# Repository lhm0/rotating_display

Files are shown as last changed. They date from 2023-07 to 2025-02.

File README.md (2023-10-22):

# Rotating Display

## Abstract: 
 The Rotating Display is a compact disc-sized device that rotates quietly using a CD motor. It features 40 LEDs that display time and weather data sourced from the internet. The device is wirelessly powered and controlled via a user-friendly web interface. It uses Arduino nano and ESP-01s microcontrollers and is easy to assemble.
 
<p align="center"> 
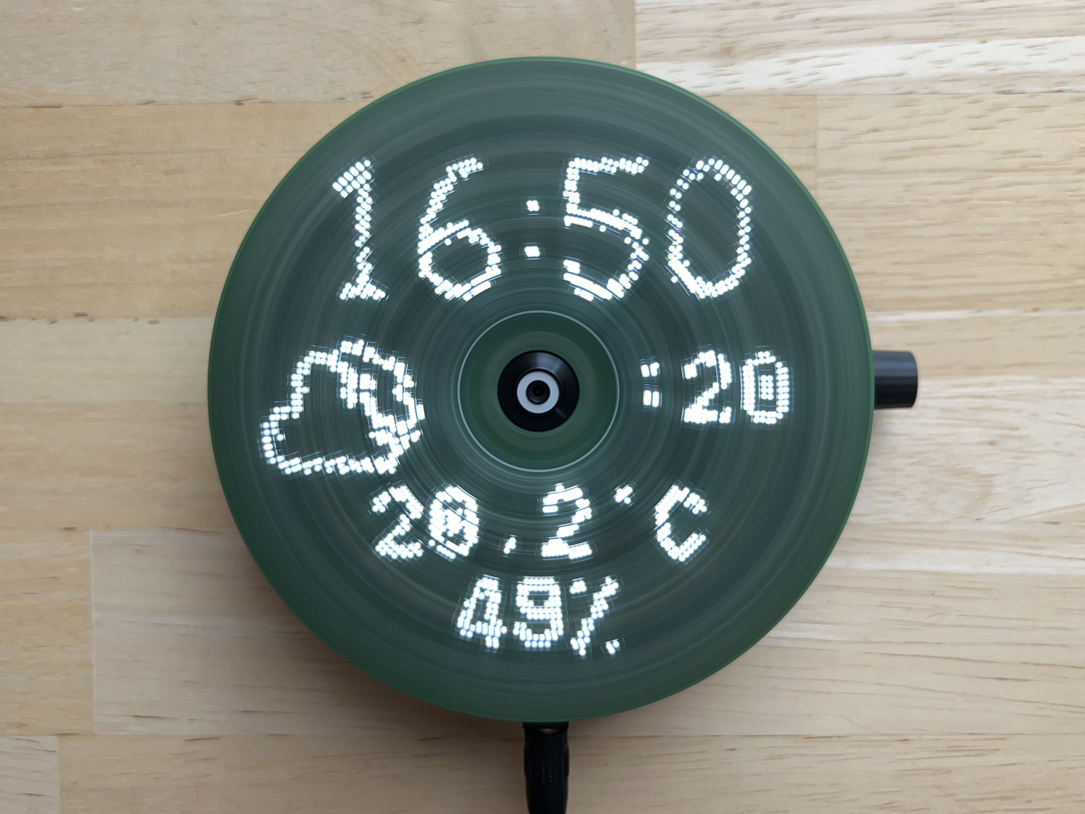
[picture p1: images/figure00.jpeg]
  
</p>

<p align="center"> 
<a href="https://youtu.be/7XahXYzULtI?si=OmdDaNnT-Jkq3F4Q" target="_blank">
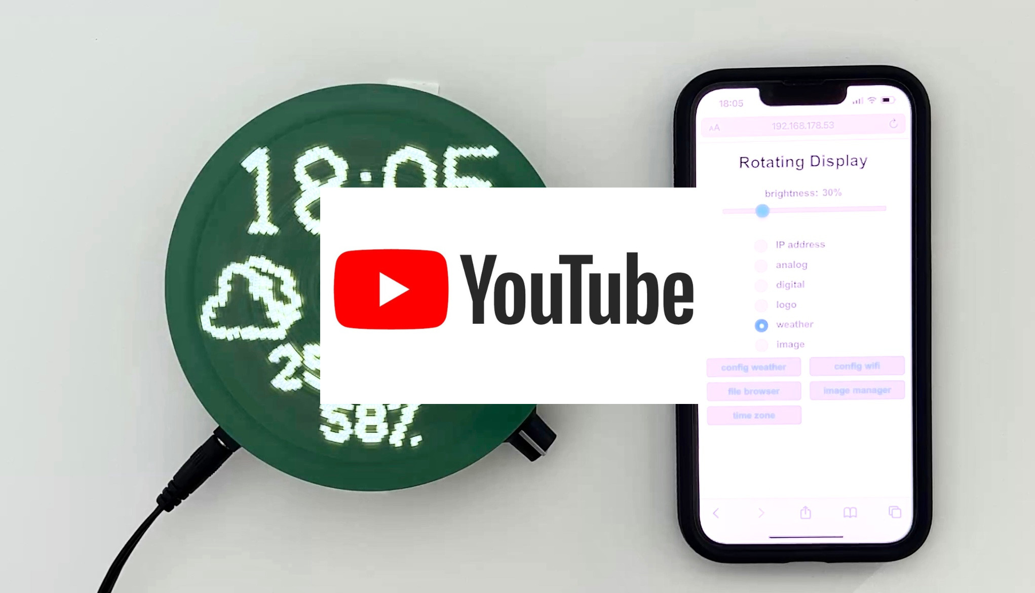
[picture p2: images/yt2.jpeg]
  
</a>
</p> 

<p align="center"> 
<a href="https://youtu.be/tHjmvry00_w?si=LjtpMpMhL_XMzbsv" target="_blank">
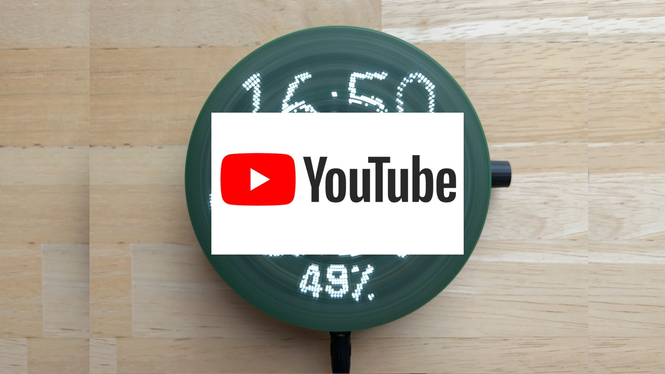
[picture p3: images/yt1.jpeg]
  
</a>
</p> 

## 1. Description of the device

The Rotating Display device comprises two primary units: a power supply unit and a display board (**figure 1**). Both are circular in design, with a diameter of 120mm, similar to the dimensions of a standard Compact Disk. The display board is rotated by a CD motor. Energy is wirelessly transmitted from the power supply unit to the display board, eliminating the need for wired connections.

<p align="center"> 
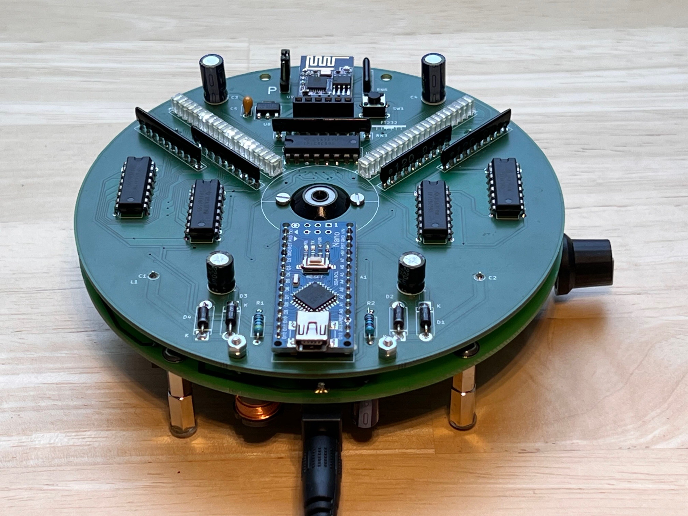
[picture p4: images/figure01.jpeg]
  
</p>

**Figure 1:  Rotating Display assembly.** The lower PCB is the power supply with wireless power transmission, the upper PCB is the display board.

The display board is equipped with two rows of LEDs, each containing 20 LEDs. This makes a total of 40 LEDs available for image representation. The LED operations are controlled by an Arduino Nano, while an ESP-01s microcontroller generates the display content. The ESP-01s maintains a Wi-Fi connection to the internet for this purpose.

This internet connection allows the device to retrieve the time from a time server, ensuring time accuracy. It also allows for the acquisition of weather data. Device operation is managed through a web interface (**figure 2**), accessible from any web browser. The interface allows users to manage login credentials, upload image files to the display, and control image and configuration files through a file manager.

<p align="center"> 
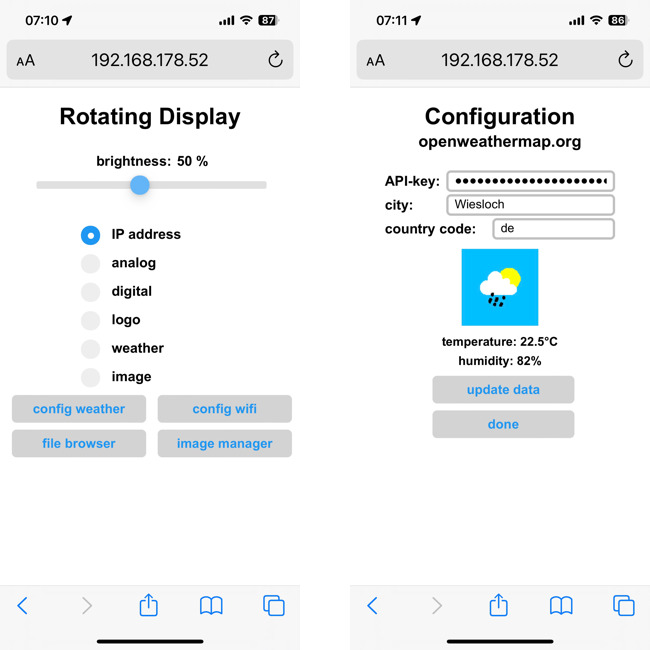
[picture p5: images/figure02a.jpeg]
  
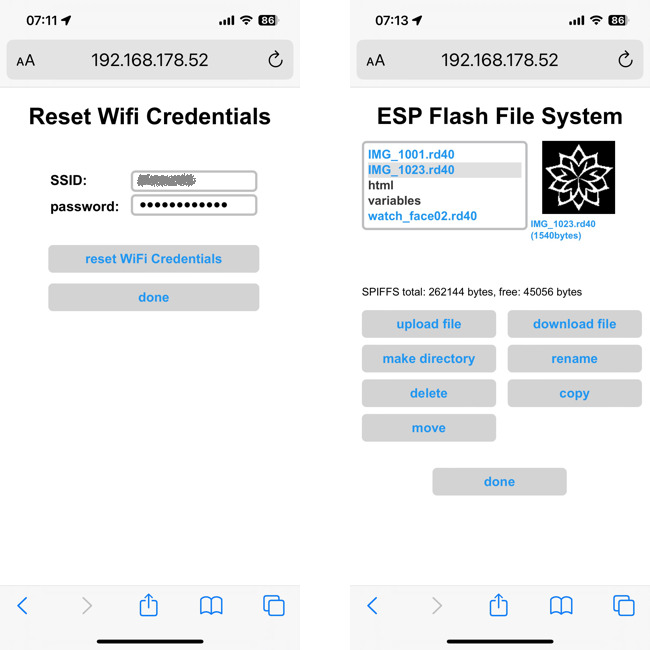
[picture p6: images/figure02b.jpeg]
  
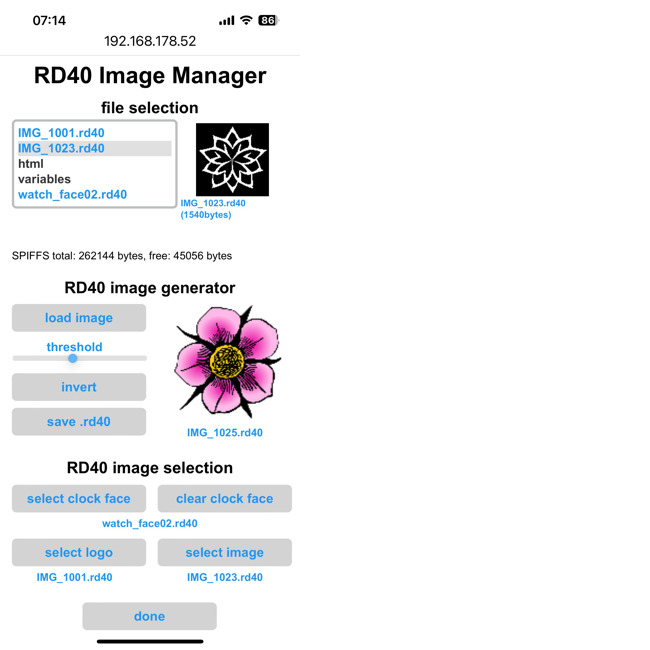
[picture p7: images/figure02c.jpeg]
  
</p>

**Figure 2:** The **web user interface** allows for operating mode selection and device configuration.

## 2. Operating modes

When switched on, the device tries to connect to a known wifi. If no valid wifi credentials are found, the unit will be configured as wifi access point. In this mode, a computer or mobile device can be connected, directly (SSID: RD40, no password). 

Once the wifi connection has been established, the unit will display its IP address on the  home page of the device (**figure 3**). Enter this address in your web browser. This will load the web user interface and will allow you to configure your local wifi.

<p align="center"> 
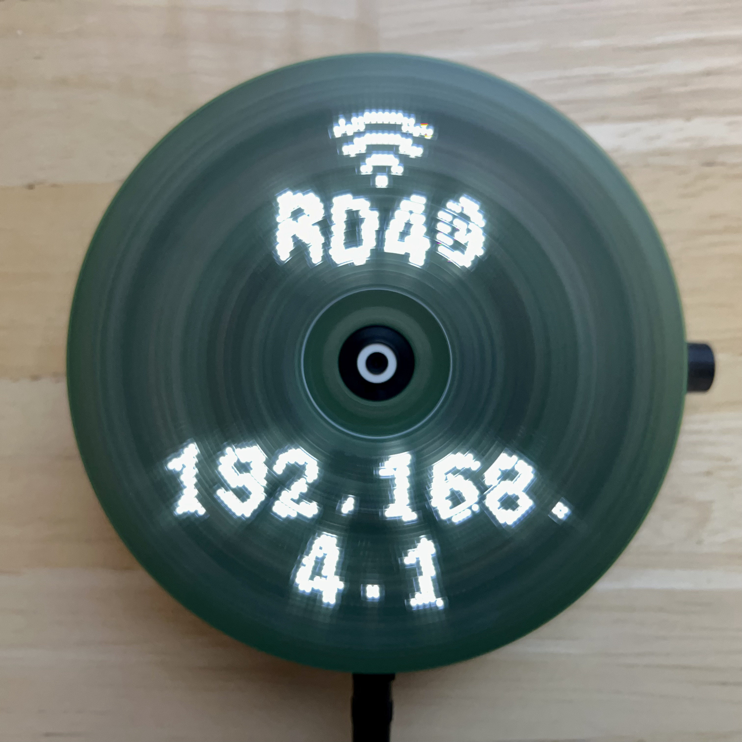
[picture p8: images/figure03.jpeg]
  
</p>

**Figure 3: home page.**

There are several operating modes that display time and weather information (**figure 4**). The logo clock mode integrates a customizable image into the clock face. The image can be easily uploaded from the user interface. The same is true for the analog clock, which uses a customizable clock face in the background.

<p align="center"> 
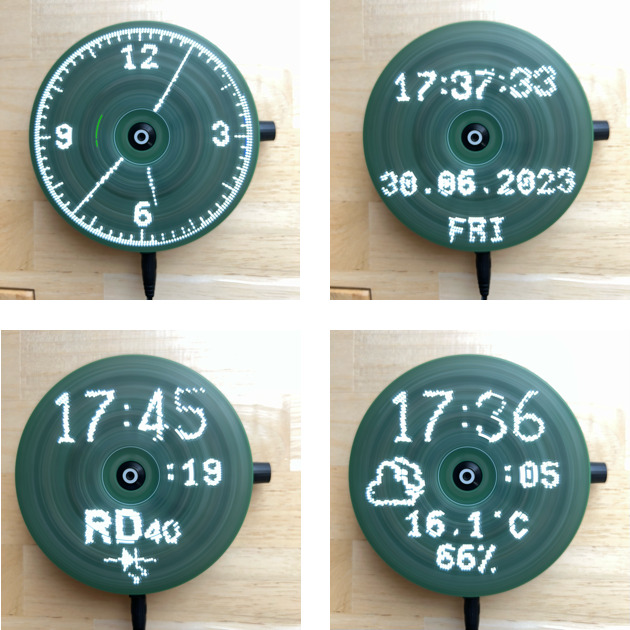
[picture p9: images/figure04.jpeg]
  
</p>

**Figure 4: operating modes.** Modes can be selected and configured through the web interface.

## 3. Mechanical design

The device consists of two assemblies: power supply and display. The power supply board is also the base plate, which can either be placed on a flat surface or hung on a wall. A standard CD motor is inserted through a recess in this board so that the CD tray above the board can accommodate the display assembly. The display board is fixed with two M2 screws. Furthermore, the base plate carries a potentiometer to control the motor speed as well as an on/off switch for the motor.

<p align="center"> 
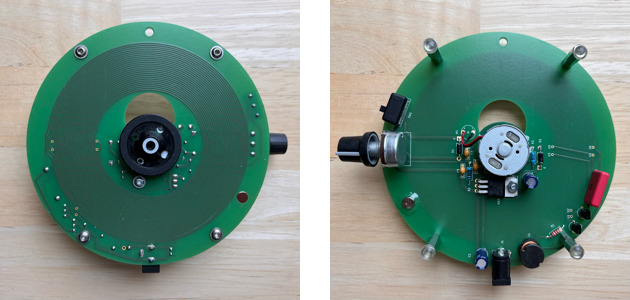
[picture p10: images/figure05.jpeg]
  
</p>

**Figure 5: Power Supply Board** with CD motor (middle), 12V power jack (lower side), and speed potentiometer

An important requirement for the display board is that the center of mass of the unit is exactly in the middle, on the axis of rotation of the motor. This is the only way to ensure smooth and vibration-free running of the display. To achieve this, the electronic components are arranged as symmetrically as possible to the vertical axis of symmetry in **figure 7**. This initially ensures that the center of gravity lies on this vertical axis. However, since the components cannot be distributed symmetrically to the horizontal axis of symmetry, the center of gravity must be shifted to the center along this axis using balancing weights. For this purpose, two M2x6mm screws with two nuts each are placed to the right and left of the Arduino nano. The balancing result is very good, but can certainly be further optimized.

<p align="center"> 
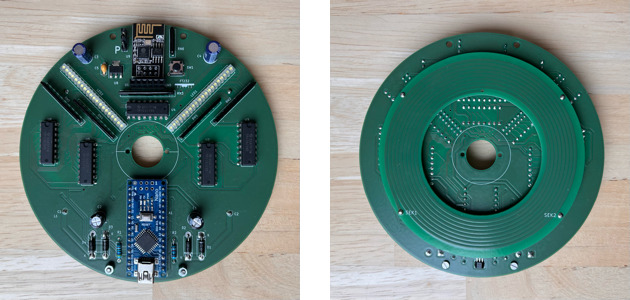
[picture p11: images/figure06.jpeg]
  
</p>

**Figure 6: Display Board.** Main components are the two LED rows, five serial shift register chips, and two microcontrollers (Arduino nano and ESP-01s). On the backside of the board the secondary coil of the wireless power supply is attached.

<p align="center"> 
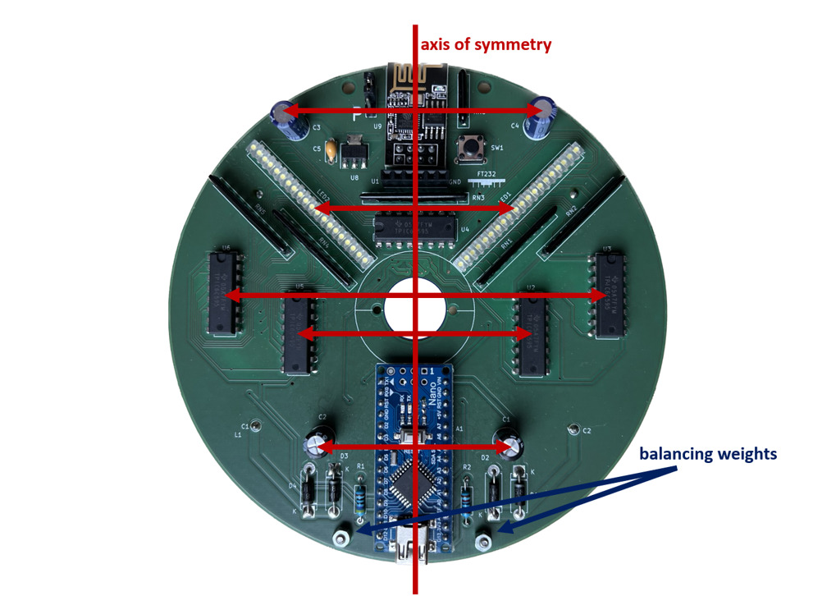
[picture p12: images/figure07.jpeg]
  
</p>

**Figure 7:** The components of the display board are arranged symmetrically to the vertical axis of symmetry. Therefore, the center of gravity is located on this axis. The vertical position of the center of gravity is adjusted to the middle by means of adjustment weights.

The two LED rows each consist of 20 discrete, rectangular LEDs. The components each have a width of 2mm and can be lined up without spacing. However, the light emitting surface of the LEDs has a diameter of only about 1mm. Thus, there is a 1mm gap between the light points. To fill these gaps, the second row of LEDs is used. It is inclined by 90 degrees along the angle of rotation. Radially, the two LED rows are shifted by 1 mm, creating a dot pattern without gaps (**figure 8**).

<p align="center"> 
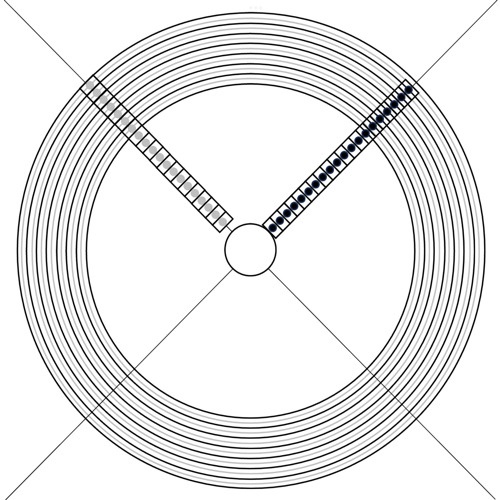
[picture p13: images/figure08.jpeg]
  
</p>

**Figure 8:** The two LED rows are displaced radially by half a LED width

The LEDs must output the image information at exactly the right position with each rotation. For spatial alignment of the image, a trigger signal is generated at a defined position for each rotation, which triggers the sequential, clocked output of the pixels. The trigger signal must be spatially very stable, otherwise no smooth image can be generated. It turned out that a Hall sensor is best suited for this purpose. It is located underneath the Arduino nano (see **figure 6**, right picture, bottom edge of the PCB). The magnet is glued into a hole of the power supply PCB (see figure 5, left picture, 4 o'clock position).

## 4. Electronics architecture

The distribution of the electronic circuitry between the two assemblies is shown in **figure 9**. The power supply assembly contains a Royer converter for wireless power transfer to the display assembly and an adjustment of the motor speed. The 40 LEDs of the display assembly are controlled by 5 shift registers (8 bits each), which in turn are supplied with clock and data by an Arduino nano via an SPI interface. The displayed content is generated by an ESP-01s microcontroller, which is connected to the internet via Wifi. It transmits its data to the Arduino nano via an I2C interface.

<p align="center"> 
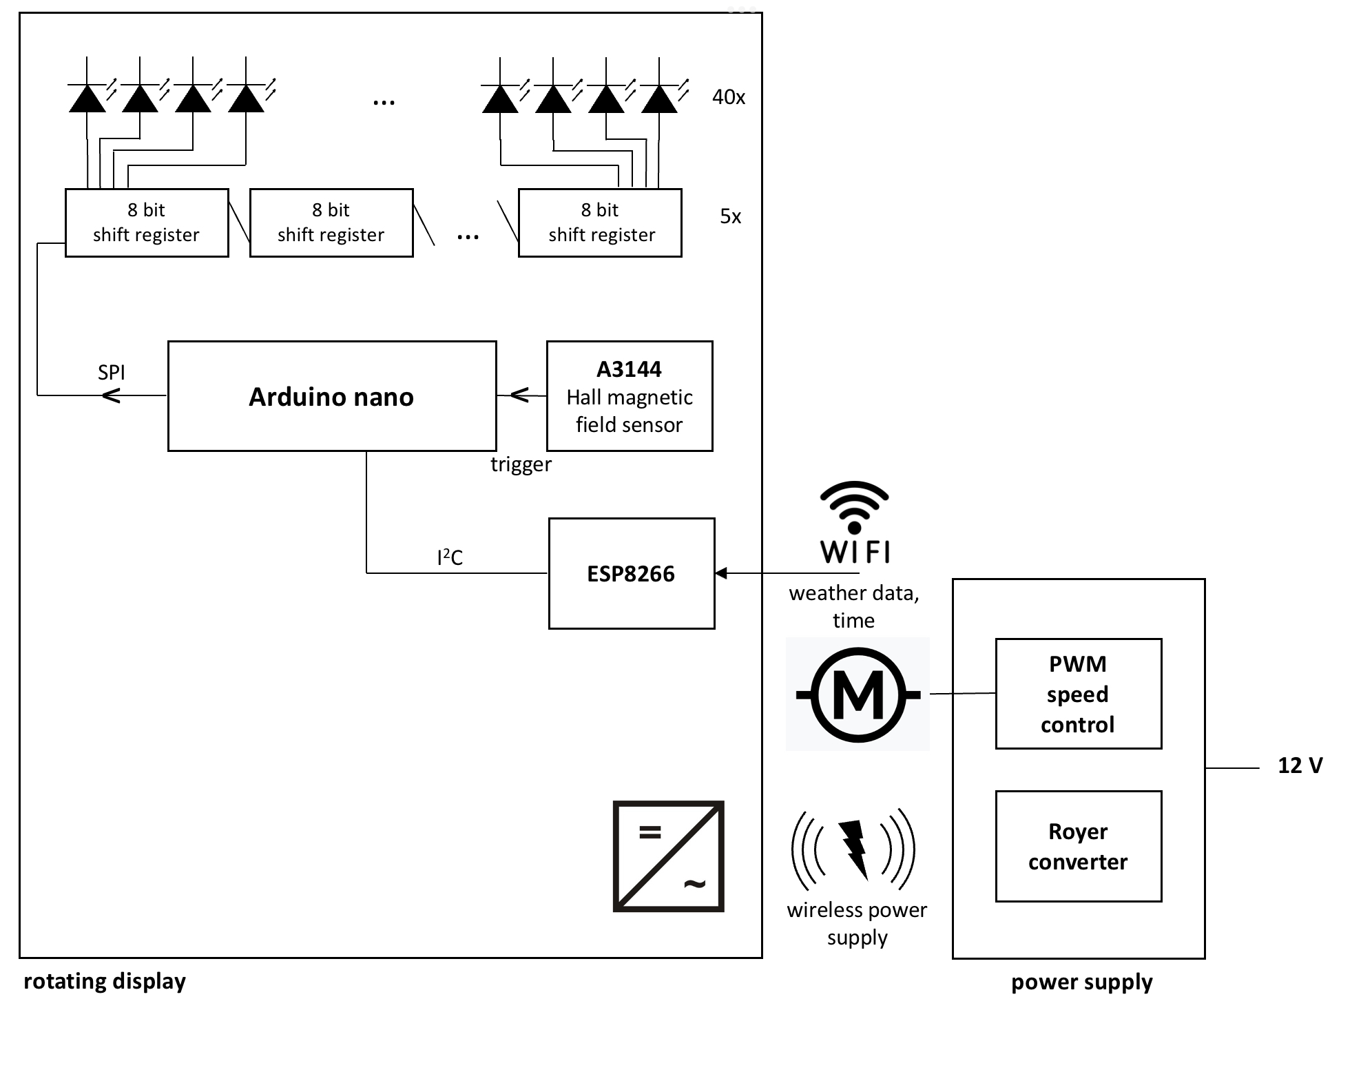
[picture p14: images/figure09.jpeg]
  
</p>

**Figure 9: electronics schematics.**

## 5. Power supply board

The core of the power supply is a Royer converter for wireless power transfer. An excellent article on the operation and design of the circuit can be found at Mikrocontroller.net (German) and the circuit was taken from there. Two transistors are alternately switched (push pull operation) so that a current flows through one half of the coil at a time. The coil belongs to a resonant circuit with a resonant frequency of about 120 kHz. The control voltage for the transistors is obtained via a coupling coil (**figure 10**). The secondary coil is located below the display board (see **figure 6**, right).

The Royer circuit uses very few components. However, the coil is quite complex. It is a bifilar coil, where the two halves are interleaved. In addition, the coupling coil must be connected with the correct polarity, otherwise the two transistors will be destroyed. In the early stages of development, the coil was wound with copper wire. However, this solution was quite difficult to reproduce, so in the final design the coils (bifilar primary coil, coupling coil, secondary coil) were implemented as a printed circuit (see **figure 5**, left and **figure 6** right). The circuit was found to have surprisingly high and perfectly adequate transmission efficiency, although the quality factor of the printed coils is inevitably compromised. The Royer converter with the printed coil assembly is absolutely safe to rebuild.

<p align="center"> 
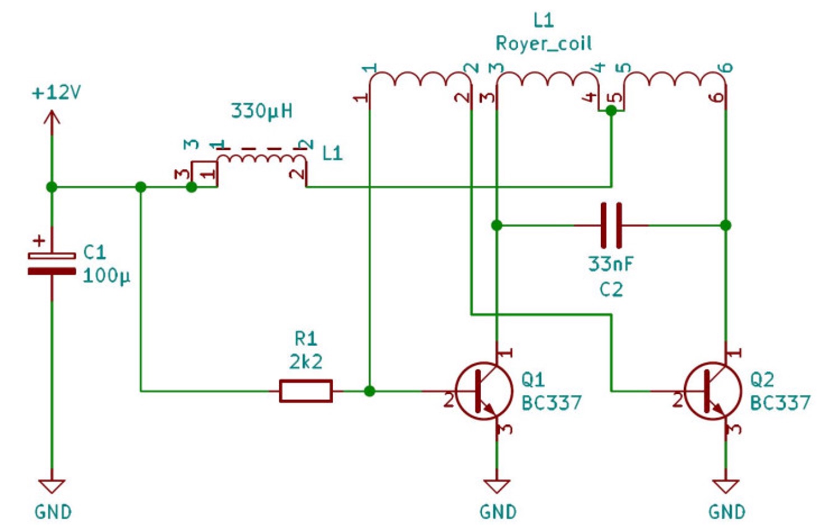
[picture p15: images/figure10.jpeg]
  
</p>

**Figure 10: Royer converter**. Compare Mikrocontroller.net for reference.

There is also a circuit for supplying the CD motor on the power supply board (**figure 11**). An LM317 voltage regulator is used to generate a variable voltage between 1.7V and 6.0V, which can be adjusted via a potentiometer. The voltage range corresponds to the specified operating range of the CD motor. The supply of the motor can be interrupted with a switch, for example to allow programming of the microcontrollers.

<p align="center"> 
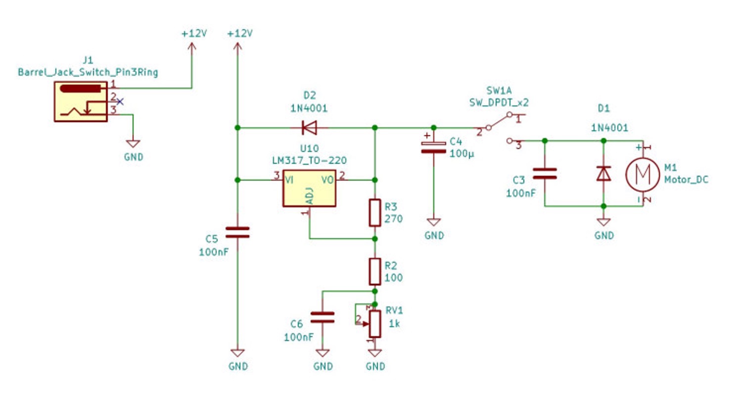
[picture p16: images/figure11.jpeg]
  
</p>

**Figure 11: variable voltage regulator** for driving the CD motor

## 6. Display Board

**a) The LEDs**

The 40 LEDs of the display board are driven by 5 cascaded 8-bit shift registers (**figure 12**). The registers load the serial data stream of the SPI interface of the Arduino nano, synchronized with the SPI clock (SRCK), and switch the parallel pattern to the LEDs when a rising edge is sent to the register clock (RCK). The TIPC6C595 shift register has open drain DMOS outputs. The LED current is set to 20mA each. The maximum current per register is therefore 160mA, which is well within specification. The brightness of the LEDs can be controlled by their duty cycle. The output enable input (G) of the register is used for this purpose. Only when this input is low, the DMOS outputs of the register are active.

The SPI interface is operated with a clock rate of 16 MHz. The 40 bits are therefore transferred in 40 x 1/16MHz = 2.5µs. Assuming a maximum rotation speed of the display of 2000 RPM, this corresponds to 30ms per revolution. At one full rotation of the display 240 pixels are output per LED. This corresponds to 125µs per pixel. Thus, the transmission time via the SPI bus (2.5µs) is significantly shorter than the display time per pixel.

<p align="center"> 
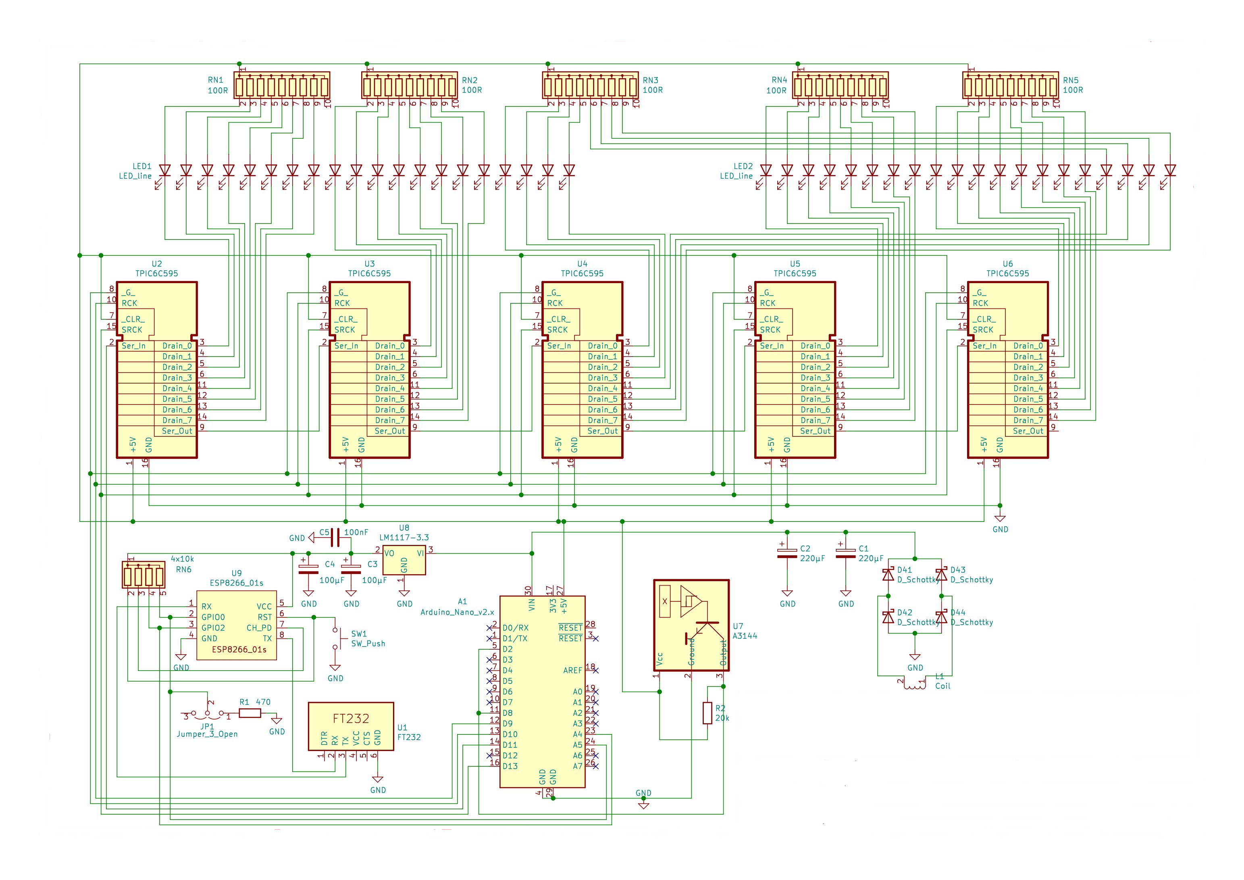
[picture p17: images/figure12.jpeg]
  
</p>

**Figure 12: circuit diagram of the display board**. Diagram also available as download and on Github.

**b) Arduino interrupts and timing**

The idea of using two microcontrollers (Arduino nano and ESP-01s) is essentially to separate the very time-critical timing of the LED control from the computationally intensive and asynchronous image generation and internet communication. In this way, the Arduino is relieved to the maximum and the display of the image is extremely stable.

The software of the Arduino programmed in C consists of two short interrupt routines. The first routine (INT0) is triggered by the Hall sensor exactly once for each full rotation (**figure 13**). This routine starts timer 1, which sets the duration for which a single row of pixels is displayed. Once the timer expires, it is automatically restarted and a second interrupt routine is triggered (INT1). In this second routine the bit pattern of the LEDs is updated. So in this way a new LED pattern appears with each expiration of timer 1. It is important that timer 1 restarts automatically (hardware controlled). Otherwise there could be a delay if the processor cannot start the interrupt routine immediately (because another routine prevents this, for example).

Another important function is to set the duration of timer 1 so that exactly 240 pixel rows per turn are output. For this purpose, the variable "tpt" (time per turn) is increased by the set value of timer 1 with each call of INT1. The routine INT0 can read tpt and thus knows the exact time duration for one revolution - even if it consists of more or less than 240 timer 1 cycles. The new time per pixel (tpt/240) is then calculated from this value and timer 1 is set accordingly.

To control the brightness of the LEDs, the threshold function of timer 1 is used: as soon as a programmable threshold is exceeded, an output of the Arduino switches. The signal is used to switch on the LEDs for the selected time. The principle is similar to the well known pulse width modulation. However, the pulses are synchronized with the pixel clock.

<p align="center"> 
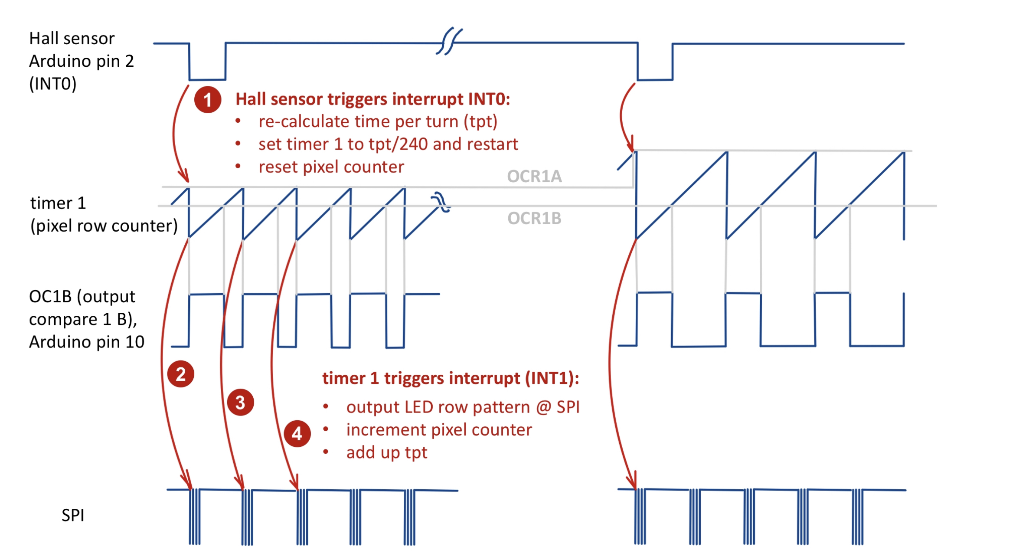
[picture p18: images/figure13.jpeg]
  
</p>

**Figure 13: Arduino interrupt timing.** Timer 1 clocks the pixel output and sets the LED brightness.

**c) ESP-01s for Internet communication and image generation**

The microcontroller ESP-01s has a Wifi module for internet communication and just two programmable input/output pins. The module is placed at the edge of the display board, because the interference field of the wireless power supply is lowest there. In previous versions of the board, the module was located in the center of the board, which caused the controller to misbehave in a way that was difficult to interpret, apparently due to an interference from the wireless power supply. This issue is fully resolved in the latest version of the display. 

Although a concern in the beginning of the development, it turned out that the fast rotation of the display does not lead to any noticeable impairment of the Wifi connection.

**d) Programming of the microcontrollers**

The Arduino nano can be programmed via its mini-USB socket. During programming the power supply of the display can be switched off (but does not have to).

Programming the ESP-01 is a bit more complicated, because it does not have an integrated USB level converter. Therefore below the microcontroller there is a 6 pin female connector to which a FT232 level converter can be connected. Note the correct orientation of the FT232! Next to the connector a small picture shows the correct orientation. The microcontoller cannot be powered by the computer during programming. Therefore the power supply of the display must be switched on. Before programming, the jumper must be plugged in position "P". Then the reset button next to the controller is pressed so that it changes to programming mode. Now the upload can be started on the computer. Afterwards the jumper is put back to its original position and the system is restarted.

Please note that the program code and the content of the flash disk (especially the code of the internet pages) have to be loaded separately. A good tutorial on how to load the Flash Disk with Visual Studio Code and platformIO can be found here: randomnerdtutorials.com

# 7. The Software of the ESP-01s

The ESP-01s handles the generation of the image data and its transmission to the Arduino nano (once per second). The displayed information (time and weather data) is retrieved from the Internet. Furthermore, the microcontroller serves as a simple HTML web server that can be accessed by any browser to control the display.

**a) Generation of the image data**

Even though the resolution of the display achieved with the 40 LEDs is relatively low, it is sufficient to display images and text upright, undistorted and therefore easily readable. The image data is generated in a rectangular pixel matrix (i.e. a cartesian coordinate system) with 110 x 110 pixels (**figure 14**). This bitmap then has to be transformed into the polar coordinate system of the rotating LED rows, before it is transferred to the Arduino. To make the transformation fast, a lookup table is used, which transforms the x,y coordinates of the bitmap into the r, theta coordinates of the rotating LED lines. The transformation also takes into account the alternating order of the LEDs between the two rows and the 90 degree angle between the two rows.

<p align="center"> 
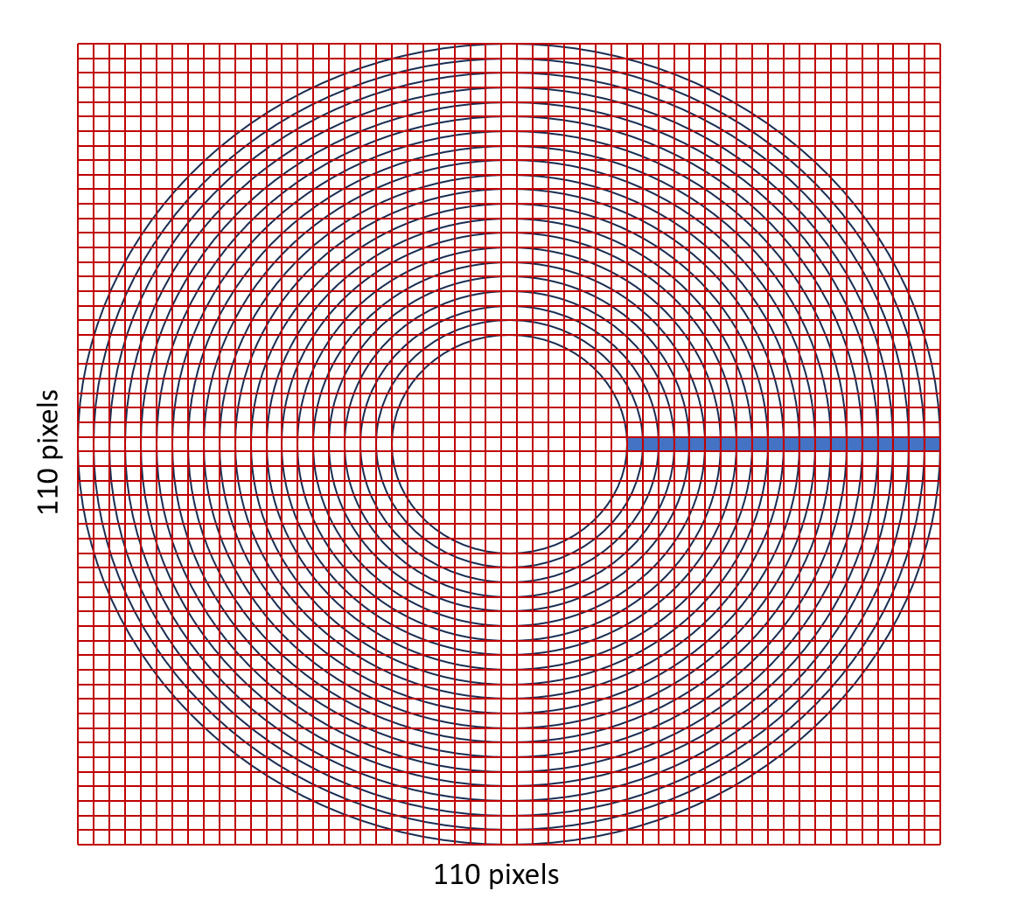
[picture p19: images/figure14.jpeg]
  
</p>

**Figure 14:** The display handles a **110x110 pixel bitmap**, which is transformed into the polar coordinate system of the rotating LED rows

**b) Control of the display via web interface**

For the implementation of the web server the library ESPAsyncWebServer is used. It has the advantage that the server activity runs in the background independent of other processes running simultaneously on the controller. The server retrieves the HTML, CSS and JS data of the displayed web pages from the local file system (LittleFS) of the microcontroller. Therefore, the web pages and the server can be implemented independently. Retrieving or modifying data is done using the HTTP GET and POST methods.

Certain parameters (brightness of the LEDs, operating mode of the display) can be set via the web interface. In addition, configuration data, such as the access data to the weather service openweather.org or the Wifi data can be edited and saved. These data are also stored in the file system LittleFS of the ESP-01 and are therefore also available after a reboot.

The LittleFS file system allows files to be organized in a directory structure and stored in the microcontroller's flash disk. The user interface of the device has a file browser with which files can be uploaded from the end device (e.g. mobile device) to the microcontroller or downloaded from the microcontroller. This is especially important to be able to load image data to the device. In addition, files and entire directories can be deleted, renamed and moved. This simplifies the organization of the flash disk considerably.

**c) Software architecture**

The ESP-01 software is written in C++. In order to keep an overview despite the large amount of software, the function blocks and the data have been divided into classes. The following is a brief description of the most important classes:

Class RD40

The class provides the central rotating display object. It manages the (private) data of the displayed image (one bit per LED). The class has methods for displaying bitmaps and for passing data to the display controller.

Class myBMP

This class creates 110x110 bit bitmaps for display. It uses private methods to print text on the bitmap, draw lines and circles, or load images.

Class WebInterface

This class manages the web user interface. Once the webInterface object has been initiated, the web server will run in the background without the need for any attention from the software. The class provides certain attributes, such as clockMode and brightness, which are managed by the web interface. The user can change configuration data via the web interface. The data is then stored as parameter files on the flash disk.

Not being a software engineer myself, the source code would most certainly benefit from a code review and revision.

**d) Development Environment**

Visual Studio Code with the PlatformIO extension was used as the development environment. The environment is much faster and more comfortable than the Arduino IDE. In addition, it can also be used for the development of the source code of the web pages.

## 8. Reproduction of the rotating display

All necessary data, such as source code, circuit diagrams, printed board layouts, parts list and sources of supply are included either in this article or in my public github repository. They may be used for non-commercial purposes, such as by hobbyists or in education, whether for reproduction or further development. Either way, please respect the terms of the license.

The device mainly uses standard components that are easy to obtain. The only exceptions could be the LEDs and the shift register (TIPC6C595, Texas Instruments). The LEDs can be purchased from LED1.de (€ 0,32 per piece, from purchase of 50 pieces). The shift register is available in large quantities from DigiKey at the time of writing. The circuit boards were manufactured at Aisler.net.

In the following some hints for the assembly are given. The assembly is simple, especially since almost only through-hole components are used. Nevertheless, good soldering skills are required. As a beginner project the device is only conditionally suitable.

<p align="center"> 
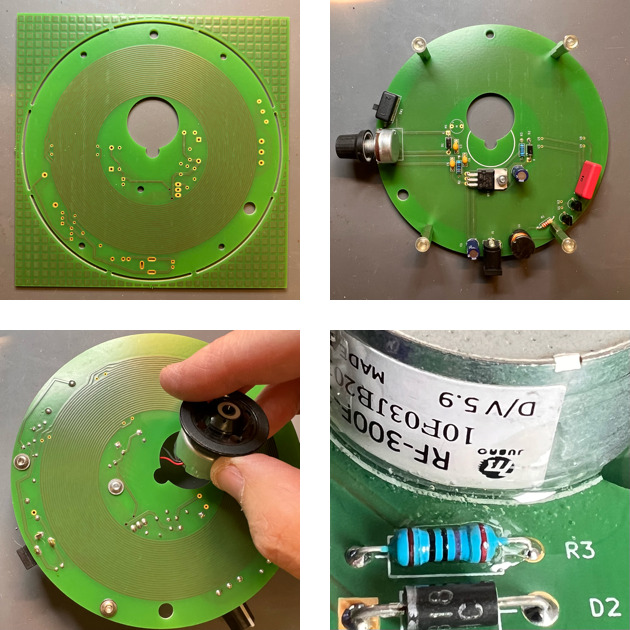
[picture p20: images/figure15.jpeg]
  
</p>

**Figure 15:** Start with the assembly of the power supply board. Insert and solder all electronic components, Afterwards, insert the CD motor from the soldering side and bond it with a fast curing two component epoxy resin.

<p align="center"> 
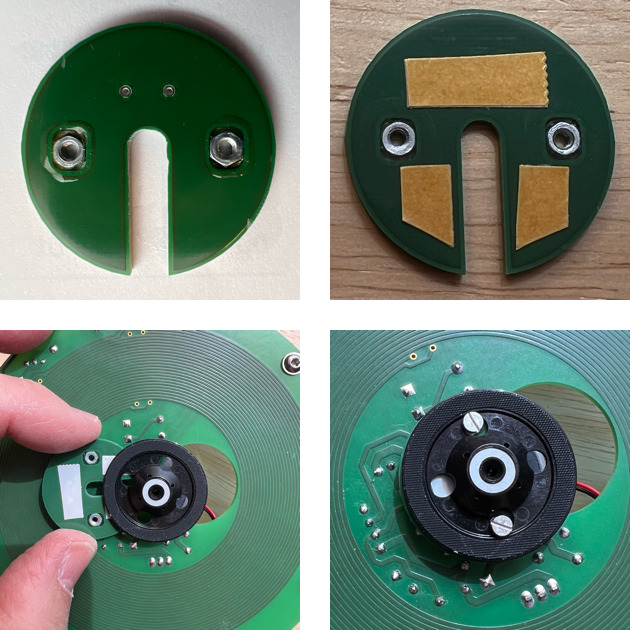
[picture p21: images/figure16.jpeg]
  
</p>

**Figure 16:** Two M2 nuts are glued into the CD tray PCB. It is attached with double-sided adhesive tape to the back side of the CD motor tray. Two M2 screws may help to bring the PCB into the right position.

<p align="center"> 
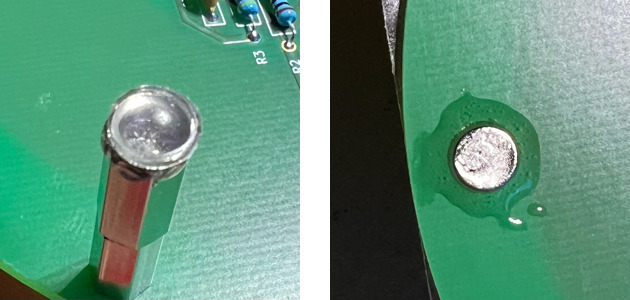
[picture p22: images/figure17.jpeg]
  
</p>

**Figure 17:** The rubber bumpers are glued to the ends of the 20 mm long bolts with the epoxy resin. The magnet is then glued into the hole provided for it. Attention: the correct orientation of the magnet (with the right side up) is very important! Make sure that the device works properly before you glue the magnet!

<p align="center"> 
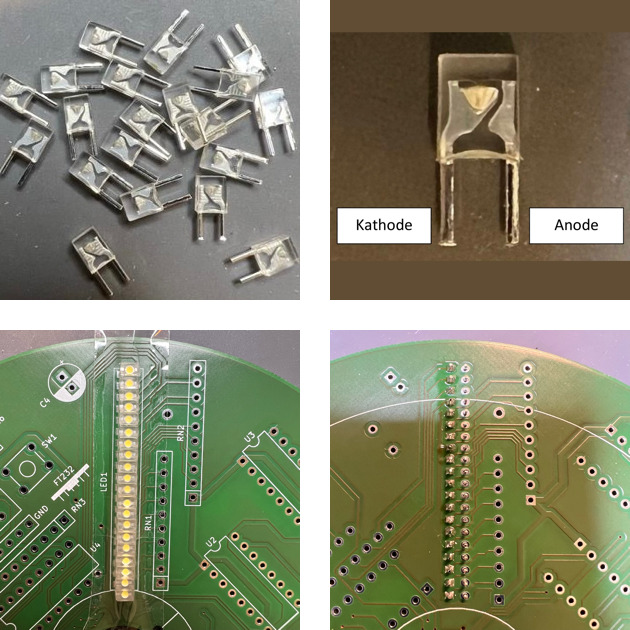
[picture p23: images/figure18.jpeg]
  
</p>

**Figure 18:** Continue with the display board assembly. First prepare the LEDs by shortening the wires. Insert them one row at a time. Hold the LEDs in place with tape before soldering. Note: The LEDs must be inserted in the correct orientation. Use the picture as a reference to identify the cathode and anode of the components. Note the marking on the PCB (A = Anode, K = Cathode).

<p align="center"> 
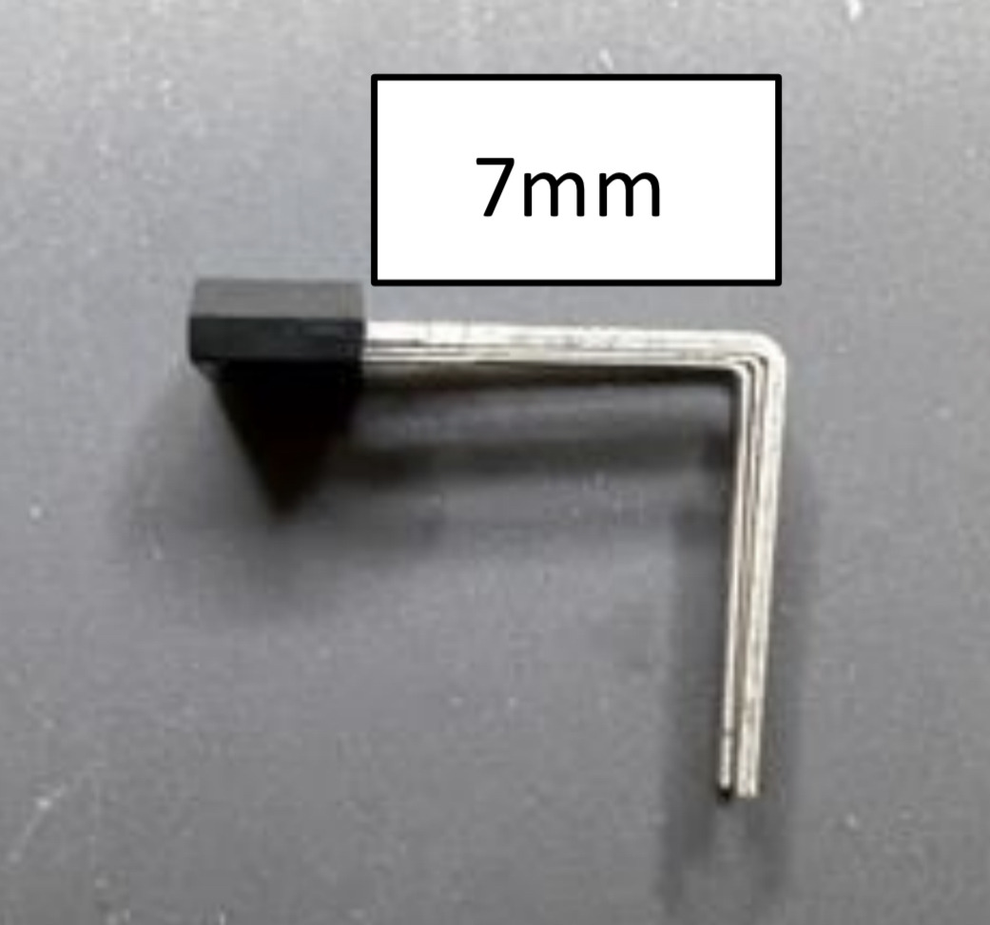
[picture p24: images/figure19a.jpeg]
  
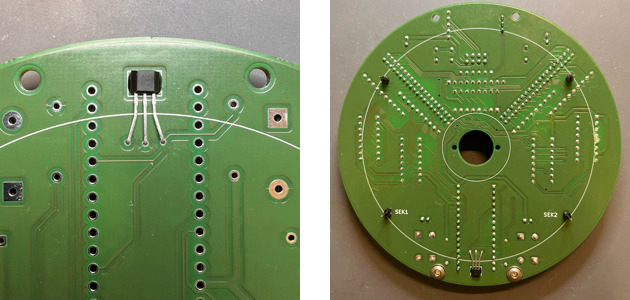
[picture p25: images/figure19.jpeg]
  
</p>

**Figure 19:** Note: The Hall sensor is the only component, that is inserted through the holes from the soldering side! It must be installed before inserting the Arduino nano, because the Hall sensor is soldered to the component side of the board, underneath the Arduino nano.

<p align="center"> 
  
</p>

**Figure 20:** When all components are installed, the secondary coil PCB can be attached using 4 pins.

## 9. Conclusions

The rotating display works according to a simple principle. However, the development of the Rotating Display device presented numerous highly interesting engineering challenges. Finding solutions for this was not only very interesting, but an opportunity to learn a wide variety of technologies. Last but not least, it was an intellectual challenge that I enjoyed a lot.

Worth mentioning are:

* Simple design with few mechanical components
* Replicable wireless power supply with printed coils
* Alternating arrangement of LEDs to achieve higher resolution
* Complete balancing of the display board to ensure vibration-free operation
* Timer controlled clocking of the LEDs and regulation of their brightness
* User-friendly interface via a standard web browser
* Retrieval of time and weather data from the internet
* Implementation of a file browser for the ESP-01’s flash disk for uploading image data
* Transparent, object-oriented structure of the ESP-01s software

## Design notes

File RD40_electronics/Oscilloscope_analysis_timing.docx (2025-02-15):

Rotating Display RD40

Shift Register Timing Analysis

1. Preparation of the board

Before you can start the analysis with the oscilloscope, you need to prepare your board by soldering wires or pins to the points of interest of the Arduino nano.

We will look at

SPI Clock GPIO 13

SPI MOSI (Data) GPIO 11

G_enable GPIO 10

Latch GPIO 9

It is probably easiest, to solder pins to the top of the Arduino header:

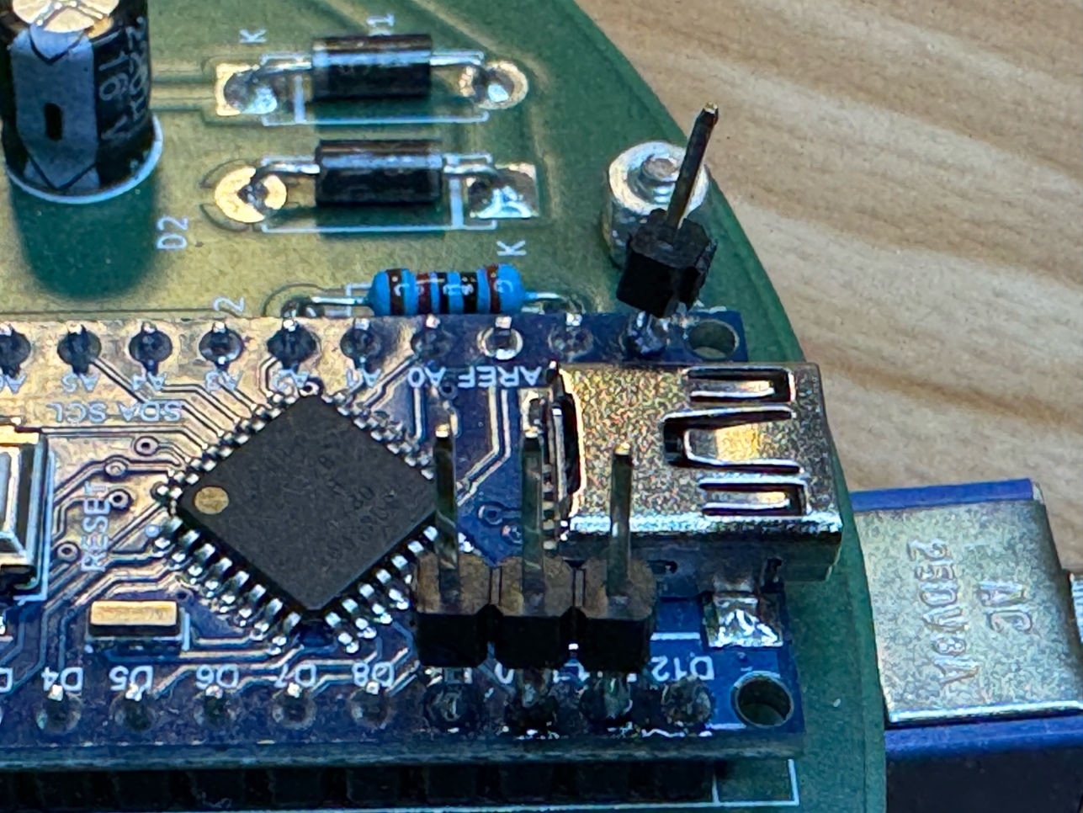
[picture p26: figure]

2. Checking the ripple of the +5V line

Start with connecting the oscilloscope to the +5V line. A good access point is Resistor R2. Connect the ground clip to the ground pin of one of the diodes:

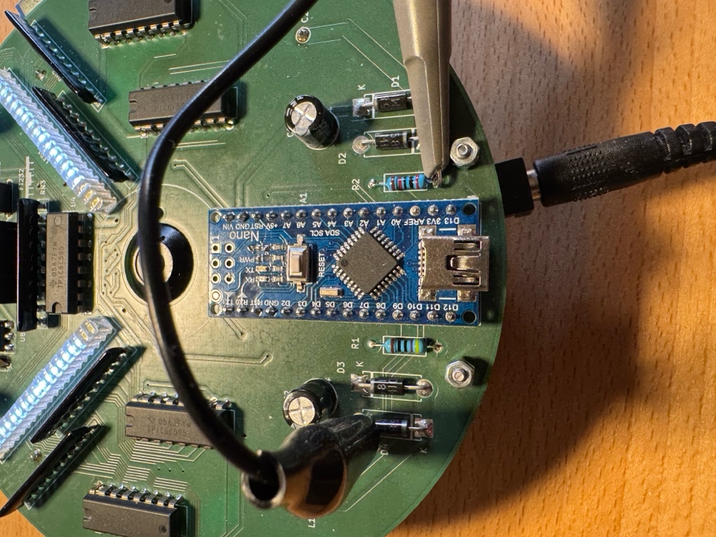
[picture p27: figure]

Use channel 1 of the oscilloscope.

Settings:
Trigger: channel 1

AC coupling

Amplification channel 1: 100 mV/cm

Time base: 4µs/cm

Adjust the trigger level until you get a stable image.

You can expect to see some noise with the frequency of the wireless power supply (about 120 kHz, period 8 µs).

This is what I got on my board:

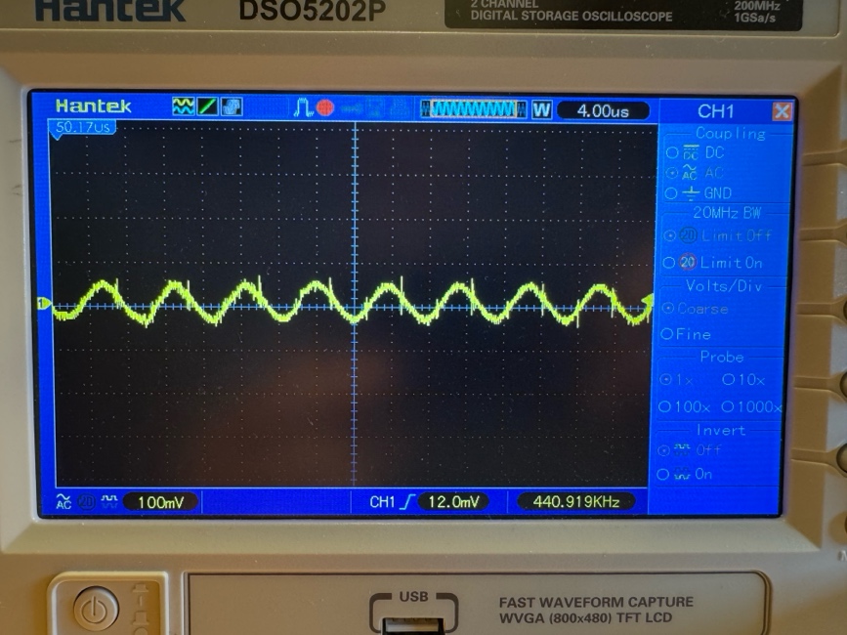
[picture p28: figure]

The amplitude of the ripple on my board is about 100 mV, which is very good. Measure the ripple on your board.

3. Checking the SPI Clock

Connect your scope to GPIO 13.

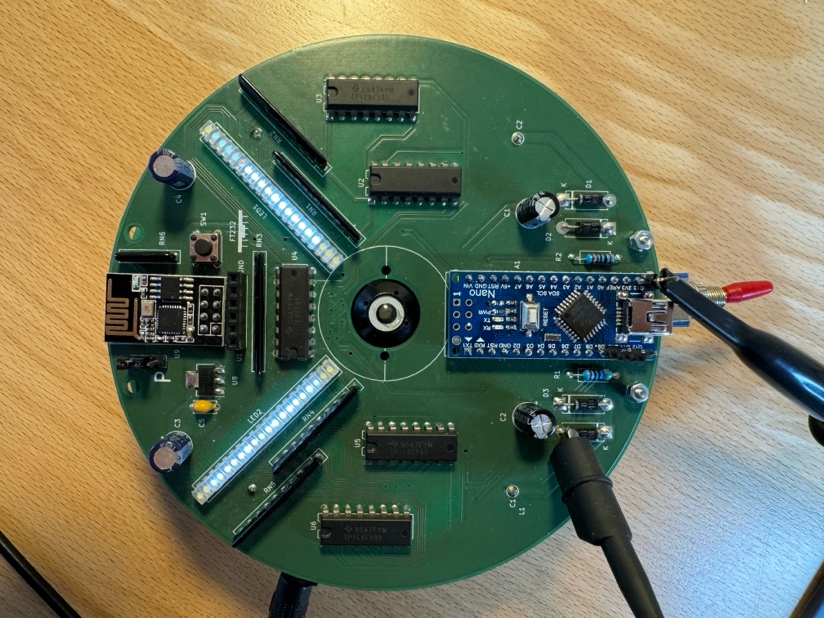
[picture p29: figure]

Settings:

Trigger: channel 1, rising edge

DC coupling

Amplification channel 1: 2V/cm or 5V/cm

Time base: 4µs/cm

Adjust the trigger level, until you get an image. The image will not be stable, as the signal is irregular. So it might be helpful, to simply stop triggering at some point and in order to do an image analysis. My scope has a button for that.

This is how the signal should look:

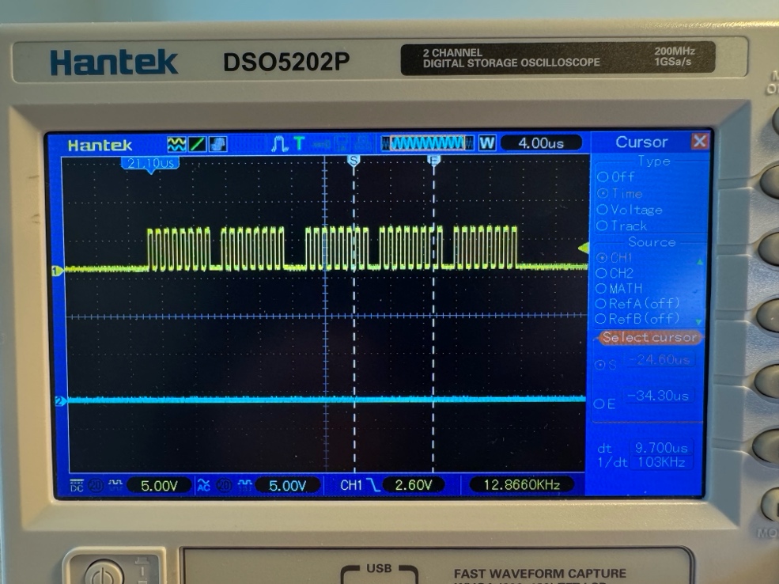
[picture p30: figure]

There are 5 bursts with 8 pulses each. These are the five bytes of data for the 40 LEDs (one byte per shift register). There is a reason, why there is a longer pause between the second and the third burst. As you can see in the Arduino code, the third byte needs more computation time.

Next we check the clock frequency.

Settings:

Trigger: channel 1, rising edge

DC coupling

Amplification channel 1: 2V/cm or 5V/cm

Time base: 400ns/cm

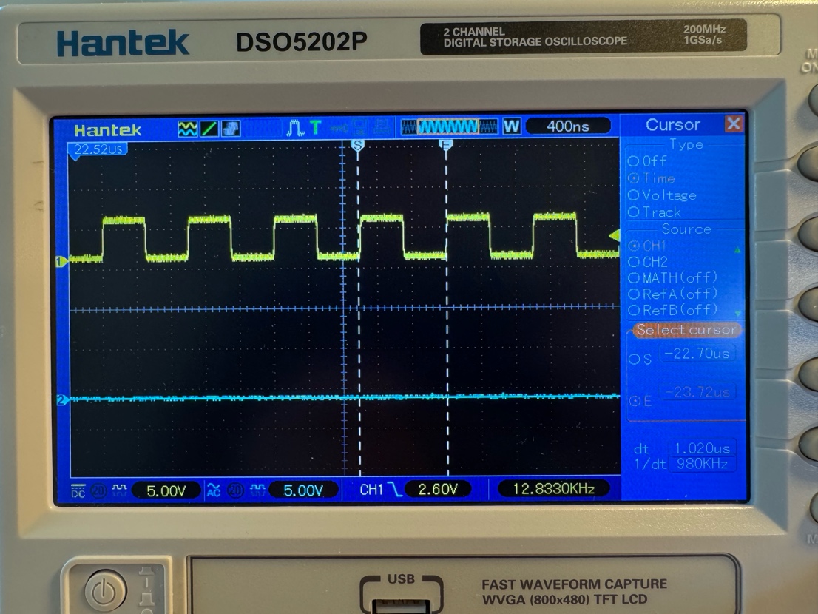
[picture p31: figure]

Measure the time of 1 period. In my case, it is 1 µs, which corresponds to 1MHz. This is the SPI clock frequency set in the (newly modified) Arduino nano program.

4. The Latch signal

A rising edge of the Latch signal causes the shift register to transfer the previously send data to the LED outputs. In other words: there needs to be a rising edge, once the data transfer to the shift registers is complete.

Connect channel 1 of the oscilloscope to clock, channel 2 to Latch:

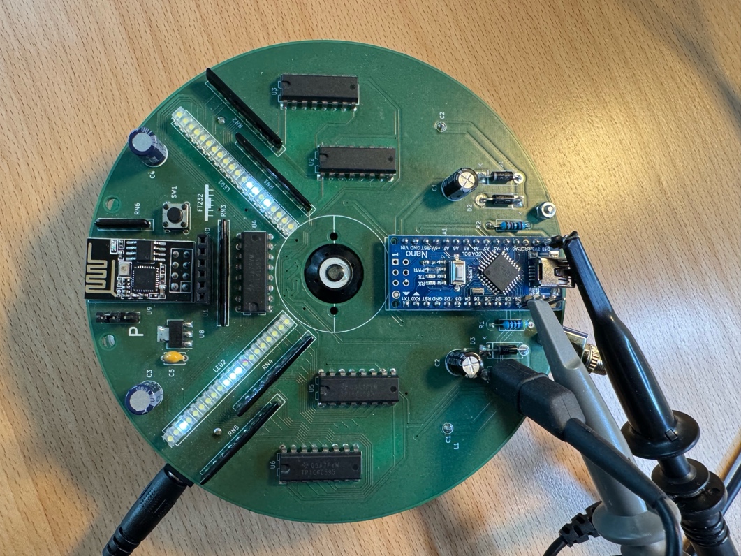
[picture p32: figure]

Settings:

Trigger: channel 1, rising edge

Channel 1 DC coupling

Amplification channel 1: 2V/cm or 5V/cm

Channel 2 DC coupling

Amplification channel 2: 2V/cm or 5V/cm

Time base: 4µs/cm

This is how the scope should look like. Note the rising edge of Latch after the 5 clock bursts.

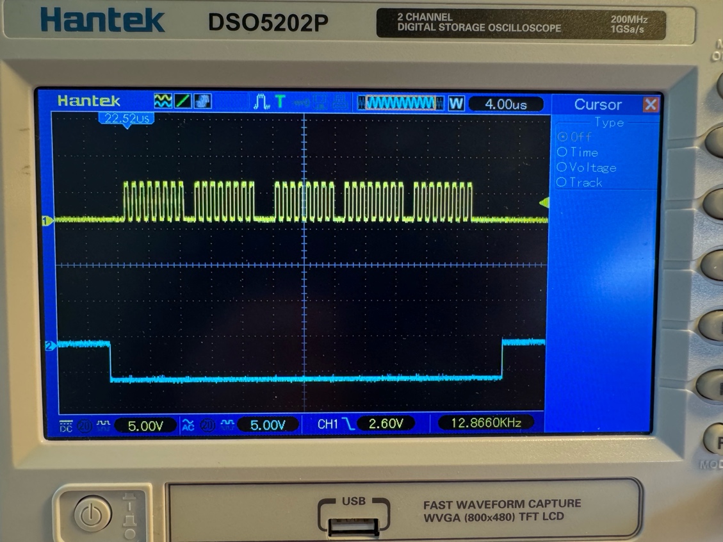
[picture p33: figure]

5. The STI data line (MOSI)

Connect channel 1 to CLK, channel 2 to SPI MOSI:

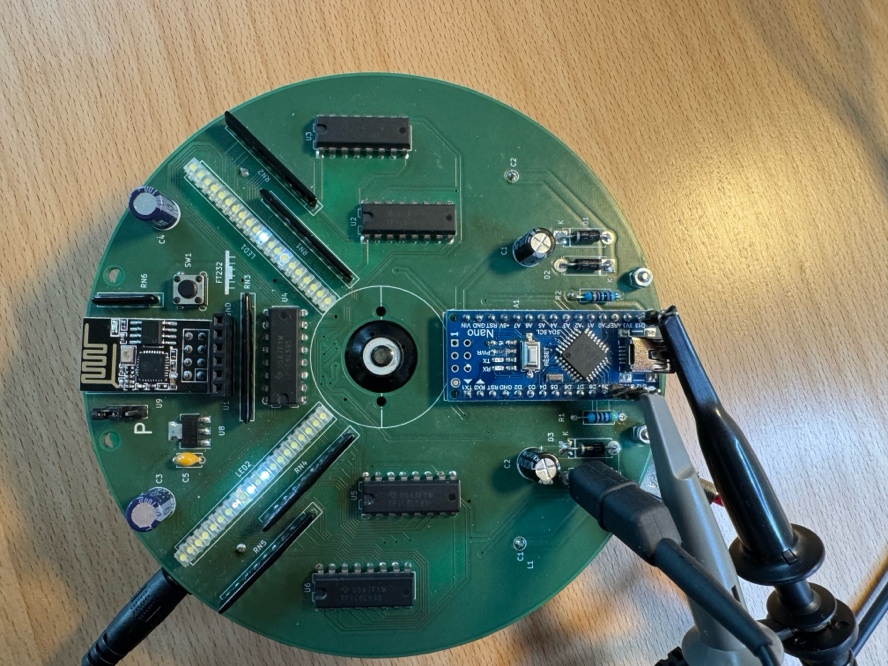
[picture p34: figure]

Settings (same as previous):

Trigger: channel 1, rising edge

Channel 1 DC coupling

Amplification channel 1: 2V/cm or 5V/cm

Channel 2 DC coupling

Amplification channel 2: 2V/cm or 5V/cm

Time base: 4µs/cm

The image will depend on whether the ESP01 sends data, or not. If so, the data line will be different from one scope image to the next. Here is a screen shot with scope on “STOP”:

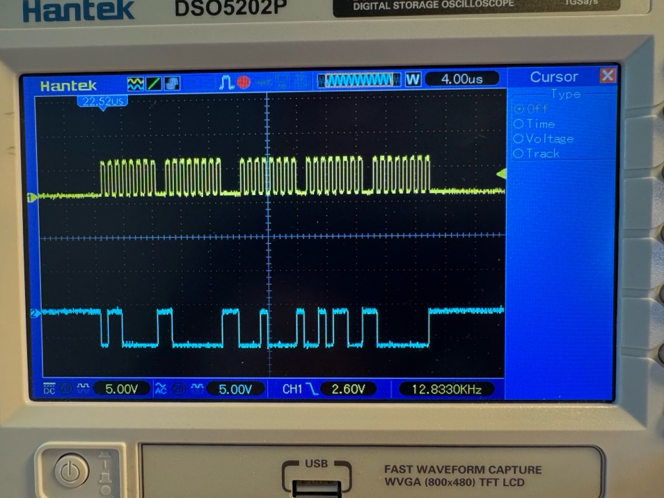
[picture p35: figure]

6. G enable signal

This signal turns on and off all LEDs. The LEDs are on, when the signal is LOW. The length of the signal is used to control the brightness of the display. It is controlled by timer 1.

Connect channel 1 to CLK, channel 2 to G_enable.

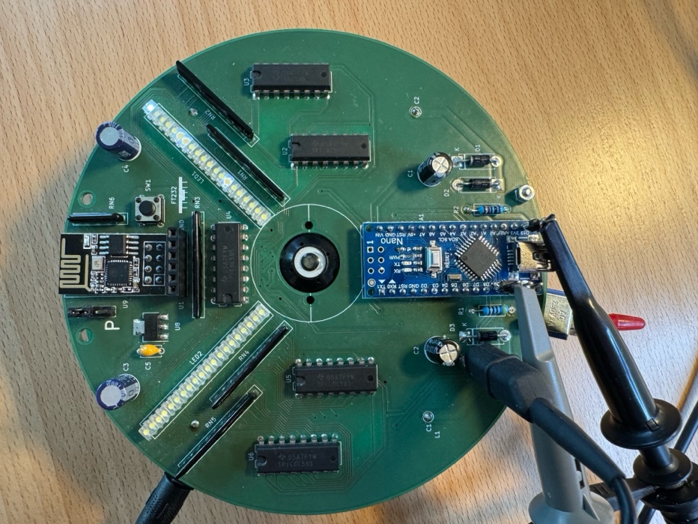
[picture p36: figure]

Settings:

Settings (same as previous):

Trigger: channel 2, rising edge

Channel 1 DC coupling

Amplification channel 1: 2V/cm or 5V/cm

Channel 2 DC coupling

Amplification channel 2: 2V/cm or 5V/cm

Time base: 8µs/cm

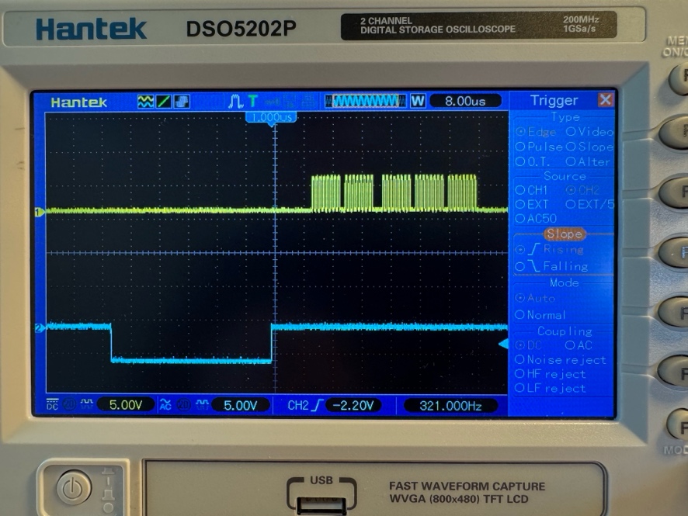
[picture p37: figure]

As you can see, the LEDs are off most of the time. Shortly after the LEDs are turned off, the data transfer of the next LED row starts.

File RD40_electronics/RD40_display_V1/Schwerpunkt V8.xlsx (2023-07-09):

 |  | Gewicht |  | x | y | x*m | y*m
Arduino | A1 | 5.1 | g | 0 | 34.54 | 0 | 176.154
Widerstand gekürzt | R1 | 0.12 | g | -12.7 | 45.08 | -1.524 | 5.4096
Widerstand gekürzt | R2 | 0.12 | g | 12.7 | 45.08 | 1.524 | 5.4096
Diode | D41 | 0.2 | g | 25 | 43.08 | 5 | 8.616
Diode | D42 | 0.2 | g | 19 | 43.08 | 3.8 | 8.616
Diode | D43 | 0.2 | g | -19 | 43.08 | -3.8 | 8.616
Diode | D44 | 0.2 | g | -25 | 43.08 | -5 | 8.616
C 220uF | C1 | 0.43 | g | 21.99 | 31 | 9.4557 | 13.33
C 220uF | C2 | 0.43 |  | -21.99 | 31 | -9.4557 | 13.33
C 100uF | C3 | 0.6 |  | 29.083 | -44.343 | 17.4498 | -26.6058
C 100uF | C4 | 0.6 | g | -29.083 | -44.343 | -17.4498 | -26.6058
C Keramik 100nF | C5 | 0.076 | g | -20.574 | -38.456 | -1.563624 | -2.922656
A3144 | U7 | 0.1 | g | 0 | 53.48 | 0 | 5.348
ESP-01s | U9 | 1.6 | g | 0 | -43.7 | 0 | -69.92 | y-Schwerpunkt geschätzt
Stecker FT232 | U1 | 0.8 | g | 0 | -31.115 | 0 | -24.892 | Masse Schätzung
IC | U2 | 1 | g | 27.94 | 5.588 | 27.94 | 5.588
IC | U3 | 1 | g | 45.847 | -3.683 | 45.847 | -3.683
IC | U4 | 1 | g | 0 | -19.558 | 0 | -19.558
IC | U5 | 1 | g | -27.94 | 5.588 | -27.94 | 5.588
IC | U6 | 1 | g | -45.847 | -3.683 | -45.847 | -3.683
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

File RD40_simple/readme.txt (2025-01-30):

RD40_simple is a simple version of the Arduino nano and the ESP01s software. It is meant for people who would like to understand, how the display and its code work.

The functionality has been reduced to a minimum. The display retrieves the time from an NTP server, converts it into local time, and displays it as text on the display. There is no web user interface.

The code does programmed in C and does not use object oriented structures, in order to keep it as simple as possible.

The data tables have been "off loaded" to a separate file "templates.cpp".

NOTE:
In order to log into you local WiFi network, you need to enter your Wifi credentials. Open the folder RD40_simple_ESP8266 in Visual Studio Code and got to lines 65 and 66. Replace 'PUT YOUR SSID HERE' with the name for your network. Replace 'PUT YOUR PASSWORD HERE' with your password.

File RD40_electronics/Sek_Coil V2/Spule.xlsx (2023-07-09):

 | M | M | S | S | R | E | alpha | x | y
1 | 0 | 0.45 | 0 | 46 | 45.55 | -45.1 | 65 | 41.2823197 | 19.70026182
1 |  | -0.45 |  | -45.1 | -44.65 | 44.2
2 |  | 0.45 |  | 44.2 | 43.75 | -43.3
2 |  | -0.45 |  | -43.3 | -42.85 | 42.4
3 |  | 0.45 |  | 42.4 | 41.95 | -41.5
3 |  | -0.45 |  | -41.5 | -41.05 | 40.6
4 |  | 0.45 |  | 40.6 | 40.15 | -39.7
4 |  | -0.45 |  | -39.7 | -39.25 | 38.8
5 |  | 0.45 |  | 38.8 | 38.35 | -37.9
5 |  | -0.45 |  | -37.9 | -37.45 | 37
6 |  | 0.45 |  | 37 | 36.55 | -36.1
6 |  | -0.45 |  | -36.1 | -35.65 | 35.2
7 |  | 0.45 |  | 35.2 | 34.75 | -34.3
7 |  | -0.45 |  | -34.3 | -33.85 | 33.4
8 |  | 0.45 |  | 33.4 | 32.95 | -32.5
8 |  | -0.45 |  | -32.5 | -32.05 | 31.6
9 |  | 0.45 |  | 31.6 | 31.15 | -30.7
9 |  | -0.45 |  | -30.7 | -30.25 | 29.8
10 |  | 0.45 |  | 29.8 | 29.35 | -28.9
10 |  | -0.45 |  | -28.9 | -28.45 | 28
11 |  | 0.45 |  | 28 | 27.55 | -27.1
11 |  | -0.45 |  | -27.1 | -26.65 | 26.2
 |  | 0.45 |  | 26.2 | 25.75 | -25.3
 |  | -0.45 |  | -25.3 | -24.85 | 24.4
 |  | 0.45 |  | 24.4 | 23.95 | -23.5
 |  | -0.45 |  | -23.5 | -23.05 | 22.6
 |  | 0.45 |  | 22.6 | 22.15 | -21.7
 |  | -0.45 |  | -21.7 | -21.25 | 20.8

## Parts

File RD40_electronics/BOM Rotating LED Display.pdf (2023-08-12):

## BOM Rotating LED Display

Power Supply Board

item # | Abbrev. | pieces | description | Source | Part Number | link | price | remark
1 | J1 | 1 CONN PWR JACK 2.1X5.5MM SOLDER | Digi-Key | EJ503A-ND | https://www.digikey.de/short/d4d54834 | € 1.37
2 | U10 | 1 LM317 | Digi-Key | 2156-LM317LZ/T1-ND | https://www.digikey.de/short/3b2j84zr | € 0.23
3 | Q1 | 1 BC337 | Digi-Key | BC33725TFRCT-ND | https://www.digikey.de/short/9hhf83c4 | € 0.35
4 | Q2 | 1 BC337 | Digi-Key | BC33725TFRCT-ND | https://www.digikey.de/short/9hhf83c4 | € 0.35
5 | D1 | 1 1N4001 | Digi-Key | 1N4004-T | https://www.digikey.de/short/9qwp2b5q | € 0.22
6 | D2 | 1 1N4001 | Digi-Key | 1N4004-T | https://www.digikey.de/short/9qwp2b5q | € 0.22
7 | R1 | 1 resistor 4k7 | generic | | | € 0.10
8 | R2 | 1 resistor 100 | generic | | | € 0.10
9 | R3 | 1 resistor 270 | generic | | | € 0.10
10 | RV1 | 1 Potentiometer 1k linear | Digi-Key | P160KN-0QD15B1K | https://www.digikey.de/short/240nt5jz | € 0.10
11 | C1 | 1 capacitor 100uF | Digi-Key | EEU-FM1E101 | https://www.digikey.de/short/ndpjmjr8 | € 0.44
12 | C2 | 1 capacitor 33nF, MKP10, 630V | Reichelt | MKP10-630 33N | https://www.reichelt.de/mkp10-pp-puls-
| | | | | kondensator-33-nf-10-630-vdc-rm-15-mkp10-
| | | | | 630-33n-p31975.html?&nbc=1 (https://www.reichelt.de/mkp10-pp-puls-kondensator-33-nf-10-630-vdc-rm-15-mkp10-630-33n-p31975.html?nbc=1) | € 0.32 critical component! do NOT change type!!
13 | C3 | 1 capacitor ceramic 100nF | generic
14 | C4 | 1 capacitor 100uF | Digi-Key | EEU-FM1E101 | https://www.digikey.de/short/ndpjmjr8 | € 0.26
15 | C5 | 1 capacitor ceramic 100nF | generic
16 | C6 | 1 capacitor ceramic 100nF | generic | | | € 0.44
17 | L1 | 1 Coil 330 uH | Reichelt | L-09HVP 330µ

https://www.reichelt.de/stehendeinduktivitaet-09hvp-ferrit-330-h-l-09hvp-330--
p255620.html?&nbc=1 (https://www.reichelt.de/stehende-induktivitaet-09hvp-ferrit-330-h-l-09hvp-330--p255620.html?&nbc=1) | € 0.87
18 | M1 | 1 CD motor with tray | Amazon, ebay | RF-300F-12350 | € 3.50
19 | magnet | 1 magnet, diameter 6mm, thickness 3 mm Amazon | Multi-Use Neodym Magnete - 6 x 3 mm

https://www.amazon.de/UTOMAG-Multi-Use-Neodym-Magnete-Aufbewahrungs/dp/B08F7HNG45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
59078103&sr=8-5 (https://www.amazon.de/UTOMAG-Multi-Use-Neodym-Magnete-Aufbewahrungs/dp/B08F7HNG45) | € 0.18
20 | screw | 2 M2x6 screw | generic
21 | M2 nuts | 2 M2 nuts | generic
22 | bolt | 4 bolt M3x20mm, female - female | Der Schraubenladen | Abstandsbolzen Messing vernickelt

https://shop.derschraubenladen.de/schrauben/abstandsbolzen/1628/abstandsbolzen/distanzhalter-distininnen/innen-messing-
vernickelt?number=SW11544.26&c=435 (https://shop.der-schraubenladen.de/schrauben/abstandsbolzen/1628/abstandsbolzen/distanzhalter-distin-innen/innen-messing-vernickelt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) | € 0.40
23 | screw | 7 screw flat head, M3x6 | Der Schraubenladen

ISO 7380-2 Linsenschraube mit Flansch Innensechskant Edelstahl A2

https://shop.derschraubenladen.de/schrauben/metrischeschrauben/schrauben-flachkopf/2144/iso-7380-2-linsenschraube-mit-flanschinnensechskant-edelstahl-
a2?number=SW12060.28&c=10 (https://shop.der-schraubenladen.de/schrauben/metrische-schrauben/schrauben-flachkopf/2144/iso-7380-2-linsenschraube-mit-flansch-innensechskant-edelstahl-a2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) | € 0.16

PLEASE UPDATE PRICES. THE BELOW IS NOT UP TO DATE. FURTHERMORE, LOW QUANTITY PRICES MIGHT BE HIGHER!!

24 | bumper | 4 bumper lens shape, diam. 6.4 mm,
| | thickness 1.9 mm | Amazon

Home Xpert 70 Stück Schutzpuffer CLEAR
Linse | https://amzn.eu/d/7VAHGcK | € 0.20
25 | PCB | 1 RD40_PS_V1 | Aisler | https://aisler.net/p/ANGDVGXG | € 19.16
26 | PCB | 1 tray | Aisler | https://aisler.net/p/DSNBUGJX | € 5.21
| | | | | € 34.28

## BOM Rotating LED Display

Display PCB

item # | Abbrev. | pieces | description | Source | Part Number | link | price | remark
1 A1 | 1 Arduino nano | AZ-Delivery | Nano V3.0 mit Atmega328 CH340

https://www.az-delivery.de/products/nano-v3-mit-ch340-arduino-
kompatibel?variant=6127202074651 (https://www.az-delivery.de/products/nano-v3-mit-ch340-arduino-kompatibel?variant=6127202074651) | € 9.59
2 U1 | 1 6 pin header | ebay | | https://www.ebay.de/itm/173482533958?mkci
| | | | d=16&mkevt=1&mkrid=707-127634-2357-
| | | | 0&ssspo=GbE0SCLXSAq&sssrc=2047675&ssuid=
| | | | lg42VTSER22&widget_ver=artemis&media=CO
| | | | PY (https://www.ebay.de/itm/173482533958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) | € 0.64
3 U2 | 1 TPIC6C595 | Digi-Key | TPIC6C595N | https://www.digikey.de/short/hhh2zfdw | € 1.41
4 U3 | 1 TPIC6C595 | Digi-Key | TPIC6C595N | https://www.digikey.de/short/hhh2zfdw | € 1.41
5 U4 | 1 TPIC6C595 | Digi-Key | TPIC6C595N | https://www.digikey.de/short/hhh2zfdw | € 1.41
6 U5 | 1 TPIC6C595 | Digi-Key | TPIC6C595N | https://www.digikey.de/short/hhh2zfdw | € 1.41
7 U6 | 1 TPIC6C595 | Digi-Key | TPIC6C595N | https://www.digikey.de/short/hhh2zfdw | € 1.41
8 U7 | 1 A3144 | Amazon | VILLCASE Hall Sensor 25 teile/los A3144 | https://amzn.eu/d/g7eitce | € 0.50
9 U8 | 1 AMS1117 3.3 SOT223 | generic | | https://amzn.eu/d/72tnrVr | € 0.50
10 U9 | 1 ESP8266-01s | AZ-Delivery | ESP8266 ESP-01S | https://www.az-delivery.de/products/esp8266-
| | | | 01 (https://www.az-delivery.de/products/esp8266-01) | € 2.95
11 D1-D40 | 40 LED white, 2x3mm | LED1.de

LED rechteckig 3x2 weiß diffus 1.800mcd WEHCW02-D1M

https://www.led1.de/shop/led-rechteckig-3x2-
weiss-diffus-1800mcd-wehcw02-d1m.html (https://www.led1.de/shop/led-rechteckig-3x2-weiss-diffus-1800mcd-wehcw02-d1m.html) | € 12.80
12 D41 | 1 1N5818 | Reichelt | 1N 5818

https://www.reichelt.de/schottkydiode-30-v-1-
a-do-41-1n-5818-p41849.html?&nbc=1 (https://www.reichelt.de/schottkydiode-30-v-1-a-do-41-1n-5818-p41849.html?&nbc=1) | € 0.05
13 D42 | 1 1N5818 | Reichelt | 1N 5818

https://www.reichelt.de/schottkydiode-30-v-1-
a-do-41-1n-5818-p41849.html?&nbc=1 (https://www.reichelt.de/schottkydiode-30-v-1-a-do-41-1n-5818-p41849.html?&nbc=1) | € 0.05
14 D43 | 1 1N5818 | Reichelt | 1N 5818

https://www.reichelt.de/schottkydiode-30-v-1-
a-do-41-1n-5818-p41849.html?&nbc=1 (https://www.reichelt.de/schottkydiode-30-v-1-a-do-41-1n-5818-p41849.html?&nbc=1) | € 0.05
15 D44 | 1 1N5818 | Reichelt | 1N 5818 | https://www.reichelt.de/schottkydiode-30-v-1-
| | | | a-do-41-1n-5818-p41849.html?&nbc=1 (https://www.reichelt.de/schottkydiode-30-v-1-a-do-41-1n-5818-p41849.html?&nbc=1) | € 0.05
16 RN1 | 1 resistor network 9x120 | Digi-Key | 4610X-101-121LF | https://www.digikey.de/short/vt12t2fc | € 0.40
17 RN2 | 1 resistor network 9x120 | Digi-Key | 4610X-101-121LF | https://www.digikey.de/short/vt12t2fc | € 0.40
18 RN3 | 1 resistor network 9x120 | Digi-Key | 4610X-101-121LF | https://www.digikey.de/short/vt12t2fc | € 0.40
19 RN4 | 1 resistor network 9x120 | Digi-Key | 4610X-101-121LF | https://www.digikey.de/short/vt12t2fc | € 0.40
20 RN5 | 1 resistor network 9x120 | Digi-Key | 4610X-101-121LF | https://www.digikey.de/short/vt12t2fc | € 0.40
21 RN6 | 1 Resistor network 4x10k | Digi-Key | 4605M-101-103LF | https://www.digikey.de/short/839dp8pc | € 0.59

PLEASE UPDATE PRICES. THE BELOW IS NOT UP TO DATE. FURTHERMORE, LOW QUANTITY PRICES MIGHT BE HIGHER!!

22 R1 | 1 resistor 470 | generic | | | € 0.10
23 R2 | 1 resistor 20k | generic | | | € 0.10
24 C1 | 1 capacitor 220uF | Digi-Key | EEU-FR1C221B | https://www.digikey.de/short/3m4wnrd0 | € 0.35
25 C2 | 1 capacitor 220uF | Digi-Key | EEU-FR1C221B | https://www.digikey.de/short/3m4wnrd0 | € 0.35
26 C3 | 1 capacitor 100uF | Digi-Key | EEU-FM1E101 | https://www.digikey.de/short/ndpjmjr8 | € 0.35
27 C4 | 1 capacitor 100uF | Digi-Key | EEU-FM1E101 | https://www.digikey.de/short/ndpjmjr8 | € 0.35
28 C5 | 1 capacitor ceramic 100nF | generic | | | € 0.15
29 pins | 1 3 pins 2.54mm | Reichelt | MPE 087-1-003

https://www.reichelt.de/stiftleisten-2-54-mm-1x03-gerade-mpe-087-1-003-
p119880.html?&trstct=pos_19&nbc=1 (https://www.reichelt.de/stiftleisten-2-54-mm-1x03-gerade-mpe-087-1-003-p119880.html?trstct=pos_19&nbc=1) | € 0.08
30 jumper | 1 jumper | Reichelt | JUMPER 2,54 SW

https://www.reichelt.de/kurzschlussbrueckeschwarz-rm-2-54-jumper-2-54-sw-
p9017.html?&trstct=pos_0&nbc=1 (https://www.reichelt.de/kurzschlussbruecke-schwarz-rm-2-54-jumper-2-54-sw-p9017.html?trstct=pos_0&nbc=1) | € 0.03
31 pins | 1 4 pins 2.54mm | Reichelt | MPE 087-1-004 | https://www.reichelt.de/stiftleisten-2-54-mm-
| | | | 1x04-gerade-mpe-087-1-004-
| | | | p119881.html?&trstct=pos_37&nbc=1 (https://www.reichelt.de/stiftleisten-2-54-mm-1x04-gerade-mpe-087-1-004-p119881.html?trstct=pos_37&nbc=1) | € 0.11
32 SW1 | 1 Omron tactile switch | Digi-Key | B3F-1020 | https://www.digikey.de/short/j00ncztz | € 0.38
33 screw | 2 M2x6 | generic | stainless steal, M2x6 | | € 0.16 Material must be stainless steel (non-magnetic!)
34 nut | 4 M2 nut | generic | M3 nut, stainless steel | | € 0.40 Material must be stainless steel (non-magnetic!)
35 PCB | 1 HiRes POV nano V8 | Aisler | | https://aisler.net/p/XYLFJKMG | € 9.58
36 PCB | 1 Sek_Coil V2 | Aisler | | https://aisler.net/p/QNEXBQDJ | € 7.18

€ 56.49

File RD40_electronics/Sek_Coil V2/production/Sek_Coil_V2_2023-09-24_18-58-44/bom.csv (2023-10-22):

Designator | Footprint | Quantity | Value | LCSC Part #
_3, _2 | Pin_2mm | 2
 | Sek_Coil_2 | 1

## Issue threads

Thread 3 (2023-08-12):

how to change the location

xfce, 2023-08-12:
Hi
I think it is default location is Freiburg, but when I change the location.txt. and country.txt, it does not work, seems still Freiburg ,de

How can i change the location to get the correct time and weather, thanks

lhm0, 2023-08-12:
Hi,
I need to understand better, what exactly you are doing. Can you provide some background on the setup? Do you have a full rotating display running? Do you use the web interface for setting the parameters? Have you entered an APIKey? Enter the city and country, hit "update data" After 10 seconds or so, the current weather for your location should show up in the web interface.
Best regards, Ludwin

xfce, 2023-08-13:
Yes I have just redesign the display PCB, fellow  guide
And I have fixed the problem,  location.txt and countroy.txt is for weather, Time zone is defined in the myesp.cpp, must change both, after chage these,  works fine, thanks
bellow is some picture.
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

Closed 2023-08-13.

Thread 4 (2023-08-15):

How to design the PCB coil

xfce, 2023-08-15:
Hi @lhm0 ,
        About the PCB coil design, is there any design guide? If I want to use this in other porjects such as some wireless charge circuit

lhm0, 2023-08-15:
 Hi (what is your name?),There is no design guide, unfortunately. I have taken the data from https://www.mikrocontroller.net/articles/Royer_Converter . Unfortunately, this article is in German.This is the table, which gives the design data of the coils:WicklungWindungszahlDrahtdurch-messer[mm]Durchmesser[mm]Induktivität[µH]Primär2x100,558070Steuer10,280---Sekundär130,556523For you reference, here is the translation into English:Wicklung -> coilWindungszahl -> number of turnsDrahtdurchmesser -> diameter of wireDurchmesser -> diameterInduktivität -> inductancePrimär -> primarySteuer -> control (feedback coil)Sekundär -> secondaryThere are many online calculators for flat coils. Here is one:translatorscafe.comPlease note, that the primary coil is a bifilar coil. It consists of two interleaved halfs.I hope this helps.Best regardsLudwinAm 15.08.2023 um 13:14 schrieb bi4wms ***@***.***>:
Hi @lhm0 ,
About the PCB coil design, is there any design guide? If I want to use this in other porjects such as some wireless charge circuit

—Reply to this email directly, view it on GitHub, or unsubscribe.You are receiving this because you were mentioned.Message ID: ***@***.***>

Closed 2023-08-22.

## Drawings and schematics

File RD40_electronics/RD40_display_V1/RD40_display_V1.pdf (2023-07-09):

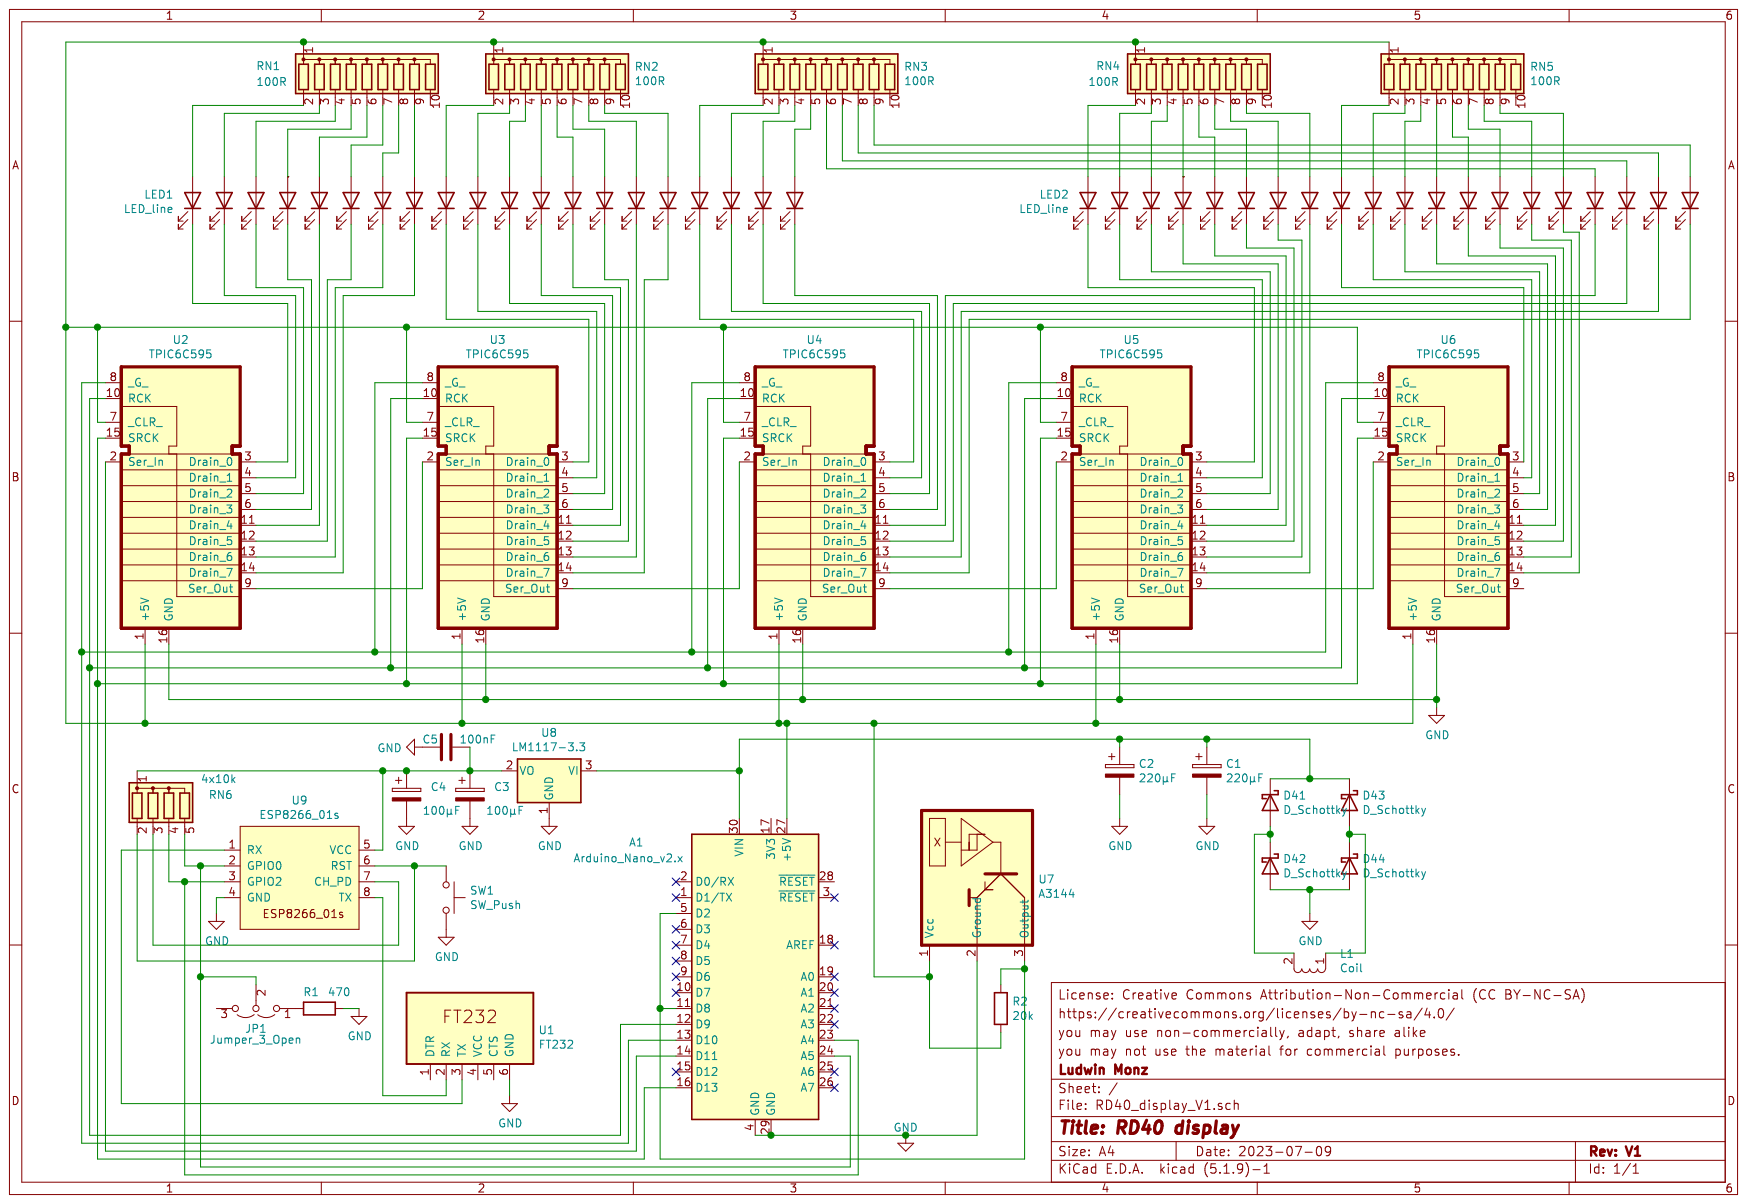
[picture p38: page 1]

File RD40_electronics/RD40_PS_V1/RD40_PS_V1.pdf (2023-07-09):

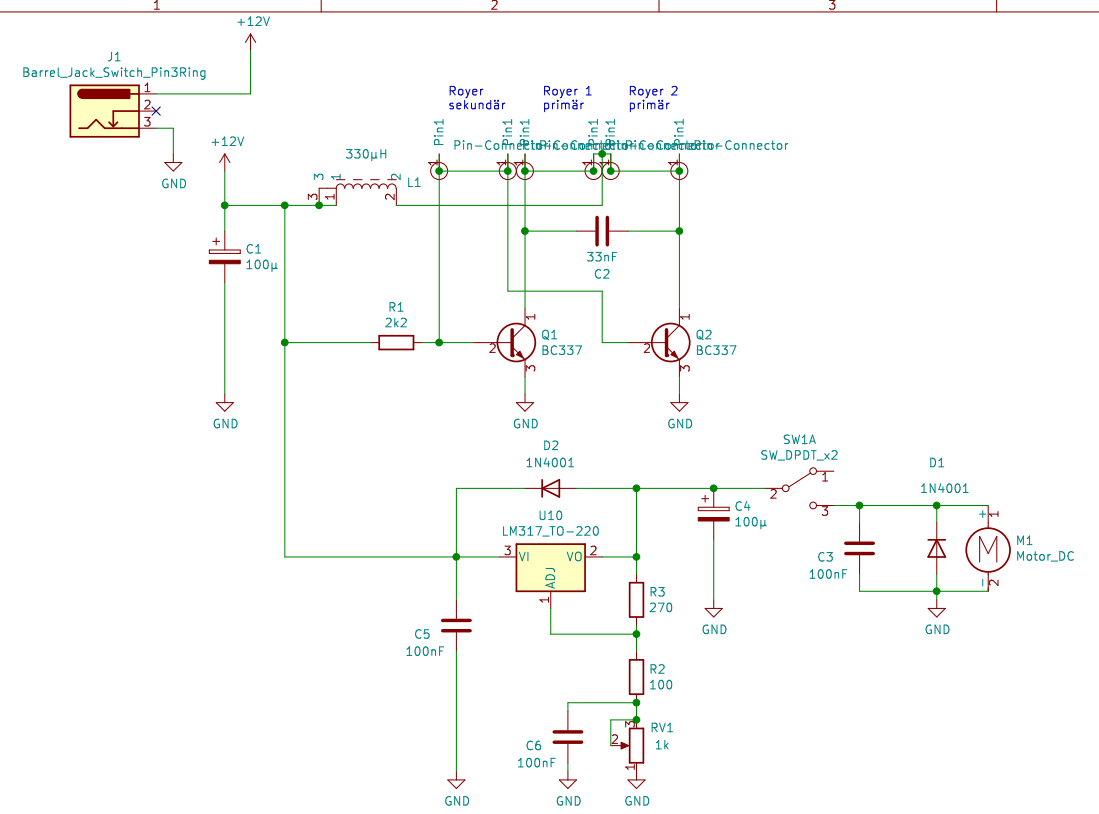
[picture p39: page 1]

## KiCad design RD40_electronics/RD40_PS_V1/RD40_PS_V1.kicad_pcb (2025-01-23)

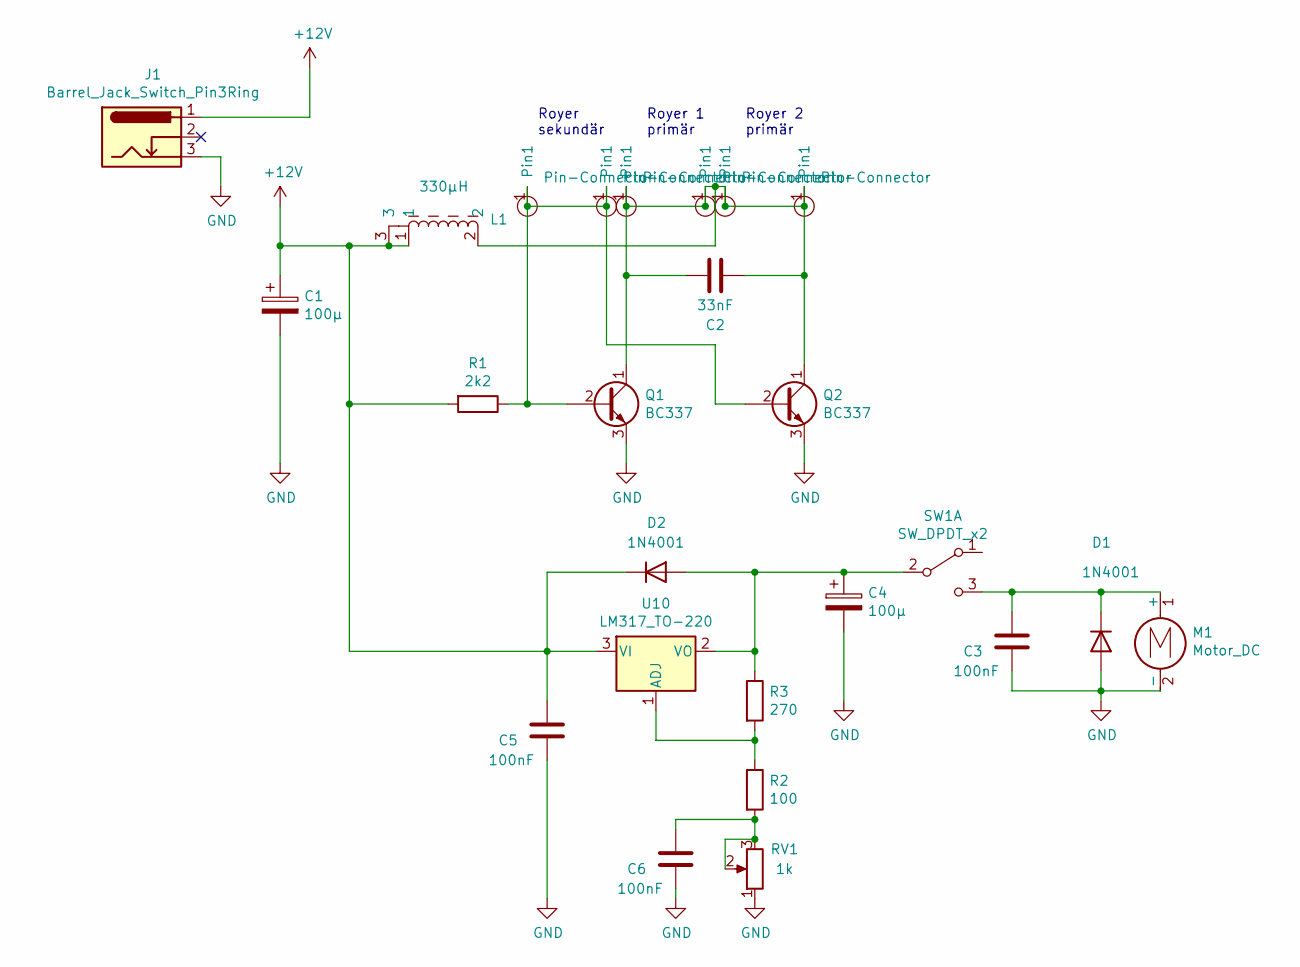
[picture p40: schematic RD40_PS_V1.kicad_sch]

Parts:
C1, C4: 100µ; CP_Radial_D6.3mm_P2.50mm
C2: 33nF; MKP10_630V
C3, C5, C6: 100nF; C_Rect_L7.0mm_W2.0mm_P5.00mm
D1, D2: 1N4001; D_DO-41_SOD81_P10.16mm_Horizontal
J1: Barrel_Jack_Switch_Pin3Ring; GRAVITECH_CON-SOCJ-2155
L1: 330µH; L_vertical12
M1: Motor_DC; motor
Q1, Q2: BC337; TO-92_Inline_Wide
R1: 2k2; R_Axial_DIN0207_L6.3mm_D2.5mm_P10.16mm_Horizontal
R2: 100; R_Axial_DIN0207_L6.3mm_D2.5mm_P10.16mm_Horizontal
R3: 270; R_Axial_DIN0207_L6.3mm_D2.5mm_P10.16mm_Horizontal
RV1: 1k; Poti_10mm
SW1: SW_DPDT_x2; Switch1
U1, U2, U3, U4, U5, U6: Pin-Connector; Pin_2mm
U10: LM317_TO-220; TO220_horizontal

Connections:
+12V: C1.1, C5.1, D2.1 (K), J1.1, L1.1, L1.3, R1.2, U10.3 (VI)
GND: C1.2, C3.2, C4.2, C5.2, C6.2, D1.2 (A), J1.3, M1.2 (-), Q1.3 (E), Q2.3 (E), RV1.1
unnamed: C2.1, C2.2, L1.2, Q1.1 (C), Q2.1 (C), U3.1, U4.1, U5.1, U6.1
unnamed: C3.1, D1.1 (K), M1.1 (+), SW1.3 (C)
unnamed: C4.1, D2.2 (A), R3.1, SW1.2 (B), U10.2 (VO)
unnamed: C6.1, R2.2, RV1.2, RV1.3
unnamed: Q1.2 (B), Q2.2 (B), R1.1, U1.1, U2.1
unnamed: R2.1, R3.2, U10.1 (ADJ)

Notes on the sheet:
Royer 2 primär
Royer sekundär
Royer 1 primär

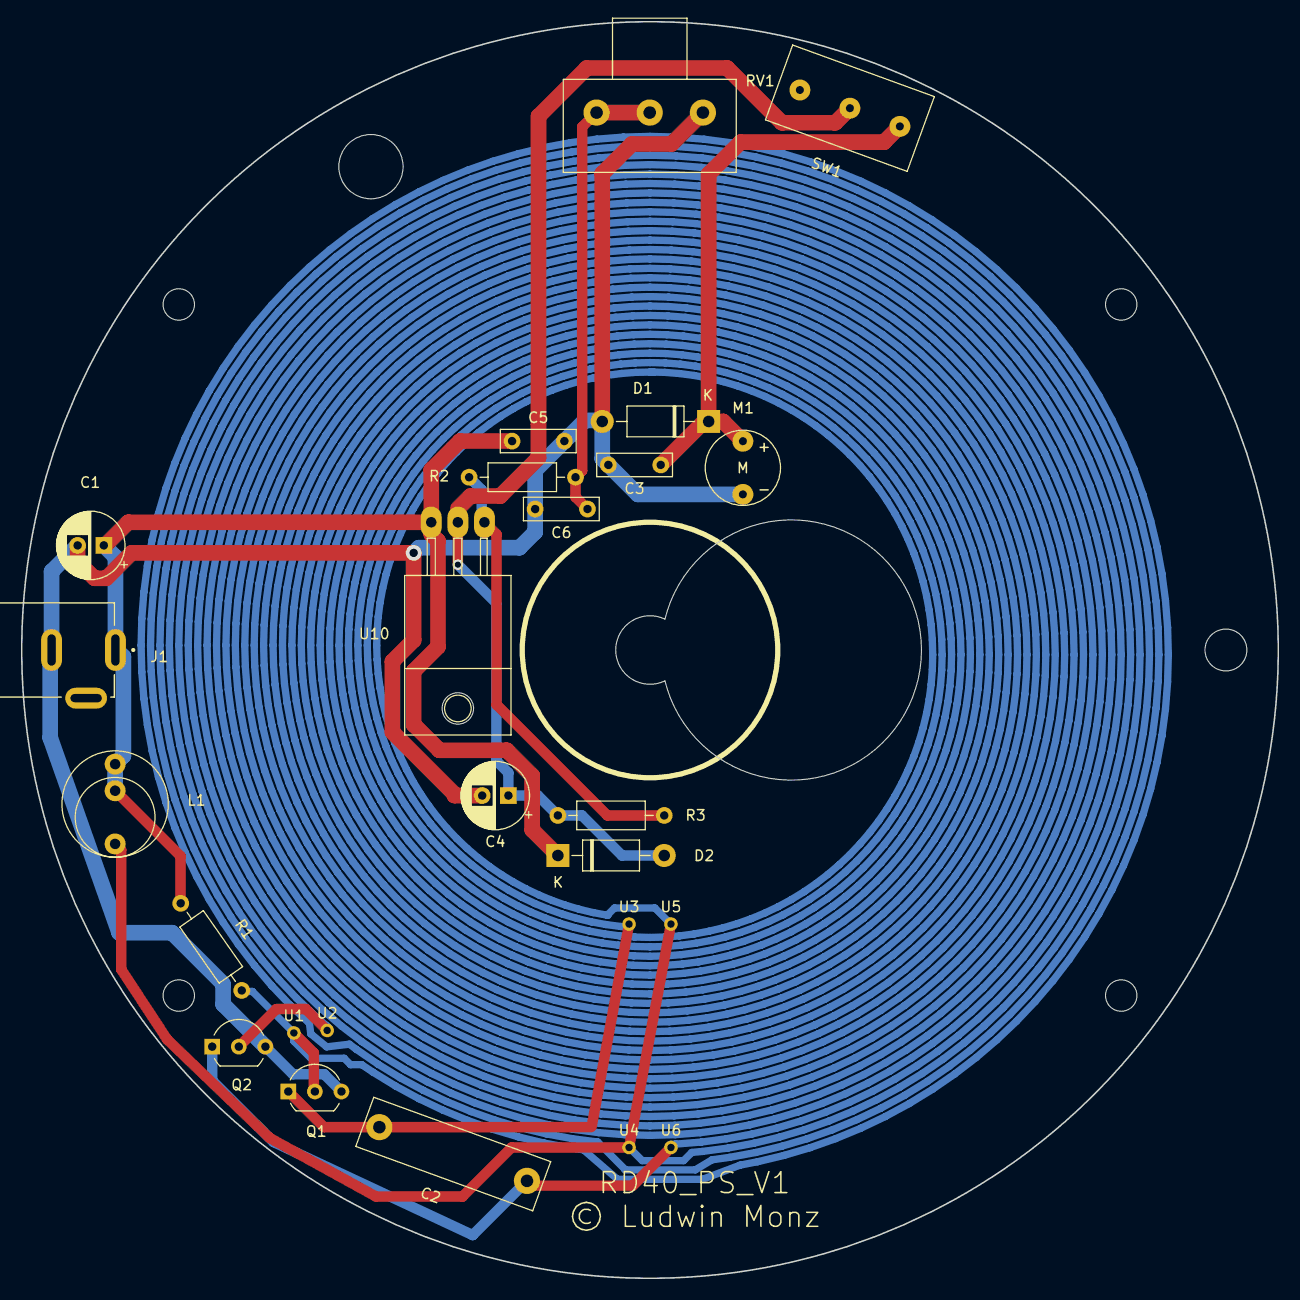
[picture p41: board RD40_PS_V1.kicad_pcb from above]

Board: 2 copper layers, 120.0 x 120.0 mm, 25 parts (0 on the bottom side), 8 nets.

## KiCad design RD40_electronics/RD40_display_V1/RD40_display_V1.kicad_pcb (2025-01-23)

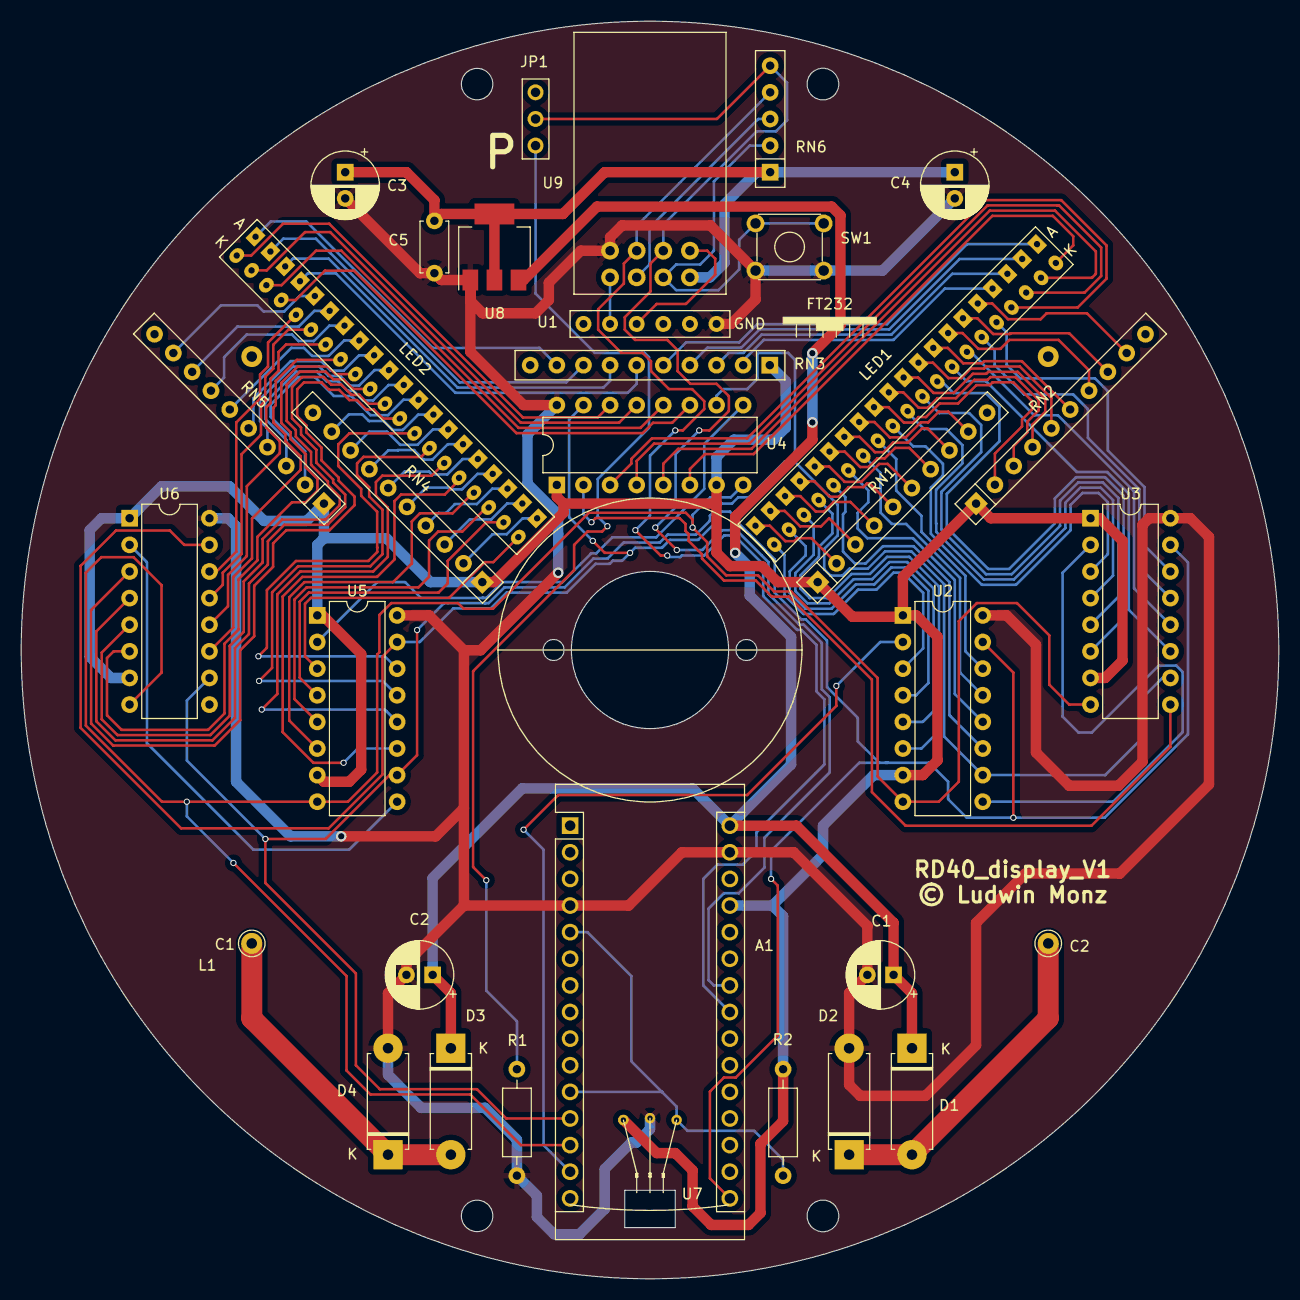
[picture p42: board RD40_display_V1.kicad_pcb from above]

Board: 2 copper layers, 120.0 x 120.0 mm, 32 parts (0 on the bottom side), 102 nets.

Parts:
A1: Arduino_Nano_v2.x; Arduino_Nano
C1, C2: 220µF; CP_Radial_D6.3mm_P2.50mm
C3, C4: 100µF; CP_Radial_D6.3mm_P2.50mm
C5: 100nF; C_Disc_D4.7mm_W2.5mm_P5.00mm
D1, D2, D3, D4: D_Schottky; D_5W_P10.16mm_Horizontal
JP1: Jumper_3_Open; Jumper_3pin
L1: Coil; coil_large
LED1: LED_line; LED_line_2.0_r
LED2: LED_line; LED_line_2.0_l
R1: 470; R_Axial_DIN0207_L6.3mm_D2.5mm_P10.16mm_Horizontal
R2: 20k; R_Axial_DIN0207_L6.3mm_D2.5mm_P10.16mm_Horizontal
RN1, RN2, RN3, RN4, RN5: 100R; R_Array_SIP10
RN6: 4x10k; R_Array_SIP5
SW1: SW_Push; OmronTaster
U1: FT232
U2, U3, U4, U5, U6: TPIC6C595; DIP-16_W7.62mm
U7: A3144
U8: LM1117-3.3; SOT-223-3_TabPin2
U9: ESP8266_01s

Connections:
GND: A1.4, A1.29, C1.2, C2.2, C3.2, C4.2, C5.2, D2.2, D4.2, R1.2, SW1.2, U1.6, U2.16, U3.16, U4.16, U5.16, U6.16, U7.2, U8.1, U9.4
unnamed: A1.5, A1.11, R2.1, U7.3
unnamed: A1.12, U2.10, U3.10, U4.10, U5.10, U6.10
unnamed: A1.13, U2.8, U3.8, U4.8, U5.8, U6.8
unnamed: A1.14, U2.2
unnamed: A1.16, U2.15, U3.15, U4.15, U5.15, U6.15
unnamed: A1.23, RN6.4, U9.3
unnamed: A1.24, JP1.2, RN6.5, U9.2
unnamed: A1.27, R2.2, RN1.1, RN2.1, RN3.1, RN4.1, RN5.1, U2.1, U2.7, U3.1, U3.7, U4.1, U4.7, U5.1, U5.7, U6.1, U6.7, U7.1
unnamed: A1.30, C1.1, C2.1, D1.1, D3.1, U8.3
unnamed: C3.1, C4.1, C5.1, RN6.1, U8.2, U9.5
unnamed: D1.2, D2.1, L1.2
unnamed: D3.2, D4.1, L1.1
unnamed: JP1.1, R1.1
unnamed: LED1.1, U2.3
unnamed: LED1.2, RN1.2
unnamed: LED1.3, U2.4
unnamed: LED1.4, RN1.3
unnamed: LED1.5, U2.5
unnamed: LED1.6, RN1.4
unnamed: LED1.7, U2.6
unnamed: LED1.8, RN1.5
unnamed: LED1.9, U2.11
unnamed: LED1.10, RN1.6
unnamed: LED1.11, U2.12
unnamed: LED1.12, RN1.7
unnamed: LED1.13, U2.13
unnamed: LED1.14, RN1.8
unnamed: LED1.15, U2.14
unnamed: LED1.16, RN1.9
unnamed: LED1.17, U3.3
unnamed: LED1.18, RN2.2
unnamed: LED1.19, U3.4
unnamed: LED1.20, RN2.3
unnamed: LED1.21, U3.5
unnamed: LED1.22, RN2.4
unnamed: LED1.23, U3.6
unnamed: LED1.24, RN2.5
unnamed: LED1.25, U3.11
unnamed: LED1.26, RN2.6
unnamed: LED1.27, U3.12
unnamed: LED1.28, RN2.7
unnamed: LED1.29, U3.13
unnamed: LED1.30, RN2.8
unnamed: LED1.31, U3.14
unnamed: LED1.32, RN2.9
unnamed: LED1.33, U4.3
unnamed: LED1.34, RN3.2
unnamed: LED1.35, U4.4
unnamed: LED1.36, RN3.3
unnamed: LED1.37, U4.5
unnamed: LED1.38, RN3.4
unnamed: LED1.39, U4.6
unnamed: LED1.40, RN3.5
unnamed: LED2.1, U5.3
unnamed: LED2.2, RN4.2
unnamed: LED2.3, U5.4
unnamed: LED2.4, RN4.3
unnamed: LED2.5, U5.5
unnamed: LED2.6, RN4.4
unnamed: LED2.7, U5.6
unnamed: LED2.8, RN4.5
unnamed: LED2.9, U5.11
unnamed: LED2.10, RN4.6
unnamed: LED2.11, U5.12
unnamed: LED2.12, RN4.7
unnamed: LED2.13, U5.13
unnamed: LED2.14, RN4.8
unnamed: LED2.15, U5.14
unnamed: LED2.16, RN4.9
unnamed: LED2.17, U6.3
unnamed: LED2.18, RN5.2
unnamed: LED2.19, U6.4
unnamed: LED2.20, RN5.3
unnamed: LED2.21, U6.5
unnamed: LED2.22, RN5.4
unnamed: LED2.23, U6.6
unnamed: LED2.24, RN5.5
unnamed: LED2.25, U6.11
unnamed: LED2.26, RN5.6
unnamed: LED2.27, U6.12
unnamed: LED2.28, RN5.7
unnamed: LED2.29, U6.13
unnamed: LED2.30, RN5.8
unnamed: LED2.31, U6.14
unnamed: LED2.32, RN5.9
unnamed: LED2.33, U4.11
unnamed: LED2.34, RN3.6
unnamed: LED2.35, U4.12
unnamed: LED2.36, RN3.7
unnamed: LED2.37, U4.13
unnamed: LED2.38, RN3.8
unnamed: LED2.39, U4.14
unnamed: LED2.40, RN3.9
unnamed: RN6.2, SW1.1, U9.6
unnamed: RN6.3, U9.7
unnamed: U1.2, U9.8
unnamed: U1.3, U9.1
unnamed: U2.9, U3.2
unnamed: U3.9, U4.2
unnamed: U4.9, U5.2
unnamed: U5.9, U6.2

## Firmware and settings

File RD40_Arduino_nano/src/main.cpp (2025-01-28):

#include <math.h>
#include <string.h>
#include <SPI.h>
#include <Wire.h>

// Constants
#define LINE_COUNT 240
#define GEAR_IMAGE_ROWS 80
#define BRIGHTNESS_UPDATE_INTERVAL_FAST 50
#define BRIGHTNESS_UPDATE_INTERVAL_SLOW 300
#define ANIMATION_UPDATE_INTERVAL 20

// Pin Definitions
const int SPI_CLOCK_PIN = 13;       // SPI Clock
const int SPI_MISO_PIN = 12;        // SPI MISO (not used in this code)
const int SPI_MOSI_PIN = 11;        // SPI MOSI
const int G_ENABLE_PIN = 10;        // G enable pin for 595 shift register
const int LATCH_PIN = 9;            // Latch pin for SPI (connects to RCLK of 595)
const int HALL_SENSOR_PIN_1 = 8;    // Hall sensor input 1
const int HALL_SENSOR_PIN_2 = 2;    // Hall sensor input 2 (INT0)

// Global Variables
long totalTimePerTurn = 0;          // Total time per rotation
long linePeriod = 1200;             // Timer interrupt every 825 µs (1.2 kHz line frequency)
long newLinePeriod;                 // Updated line period
int brightness = 50;                // Brightness in %
bool updateBrightness = true;       // Flag to recalculate PWM setting
double R, S;                        // Variables for brightness linearization
long pwmSet;                        // PWM setting for brightness control

int lineCounter0 = 60;              // Counter for displayed lines (1/4 turn ahead of lineCounter1)
int lineCounter1 = 0;               // Counter for displayed lines
int lineCounter2 = 0;               // Counter for lines after trigger
int lineOffset = 168;               // Clock orientation (12 is up)
int lastReceivedLine = 255;         // Last received line index

uint8_t lineData[LINE_COUNT][5] = {0}; // Buffer for line data

long lastBrightnessUpdateTime;      // Timestamp for brightness update
long lastAnimationUpdateTime;       // Timestamp for animation update

bool animationMode = true;          // Flag to enable/disable animation
int animationAngle = 0;             // Current angle for animation

// I2C Buffer
unsigned char i2cBuffer[16];        // Buffer for I2C received data
int receiveEventFlag = 0;           // Flag to indicate I2C receive event

// Gear Image Data (stored in PROGMEM)
const PROGMEM uint8_t gearImage[GEAR_IMAGE_ROWS][5] = {
  {0xFF, 0xFF, 0x00, 0xFF, 0xFF}, {0xFF, 0xFF, 0x11, 0xFF, 0xFF}, {0xFF, 0xFF, 0x73, 0xFF, 0xFF}, {0xFF, 0xFF, 0x7F, 0xFF, 0xFF}, {0xFF, 0xFF, 0xFF, 0xFF, 0xFF}, {0xFF, 0xFF, 0xFF, 0xFF, 0xFF}, {0xFF, 0xFF, 0x7F, 0xFF, 0xFF}, {0xFF, 0xFF, 0x73, 0xFF, 0xFF}, {0xFF, 0xFF, 0x11, 0xFF, 0xFF}, {0xFF, 0xFF, 0x00, 0xFF, 0xFF},
  {0x0F, 0xF0, 0x00, 0x07, 0xF8}, {0x07, 0xF0, 0x00, 0x07, 0xF0}, {0x07, 0xE0, 0x00, 0x03, 0xF0}, {0x03, 0xE0, 0x00, 0x03, 0xE0}, {0x03, 0xE0, 0x00, 0x03, 0xE0}, {0x03, 0xE0, 0x00, 0x03, 0xE0}, {0x03, 0xE0, 0x00, 0x03, 0xE0}, {0x03, 0xE0, 0x00, 0x03, 0xE0}, {0x03, 0xE0, 0x00, 0x03, 0xE0}, {0x03, 0xE0, 0x00, 0x03, 0xE0},
  {0x03, 0xE0, 0x00, 0x03, 0xE0}, {0x03, 0xE0, 0x11, 0x03, 0xE0}, {0x03, 0xE0, 0x73, 0x03, 0xE0}, {0x03, 0xE0, 0x7F, 0x03, 0xE0}, {0x03, 0xE0, 0xFF, 0x03, 0xE0}, {0x03, 0xE0, 0xFF, 0x03, 0xE0}, {0x03, 0xE0, 0x7F, 0x03, 0xE0}, {0x03, 0xE0, 0x73, 0x03, 0xE0}, {0x03, 0xE0, 0x11, 0x03, 0xE0}, {0x03, 0xE0, 0x00, 0x03, 0xE0},
  {0x03, 0xE0, 0x00, 0x03, 0xE0}, {0x03, 0xE0, 0x00, 0x03, 0xE0}, {0x03, 0xE0, 0x00, 0x03, 0xE0}, {0x03, 0xE0, 0x00, 0x03, 0xE0}, {0x03, 0xE0, 0x00, 0x03, 0xE0}, {0x03, 0xE0, 0x00, 0x03, 0xE0}, {0x03, 0xE0, 0x00, 0x03, 0xE0}, {0x03, 0xE0, 0x00, 0x03, 0xE0}, {0x03, 0xE0, 0x00, 0x03, 0xE0}, {0x03, 0xE0, 0x00, 0x03, 0xE0},
  {0x03, 0xE0, 0x00, 0x03, 0xE0}, {0x03, 0xE0, 0x11, 0x03, 0xE0}, {0x03, 0xE0, 0x73, 0x03, 0xE0}, {0x03, 0xE0, 0x7F, 0x03, 0xE0}, {0x03, 0xE0, 0xFF, 0x03, 0xE0}, {0x03, 0xE0, 0xFF, 0x03, 0xE0}, {0x03, 0xE0, 0x7F, 0x03, 0xE0}, {0x03, 0xE0, 0x73, 0x03, 0xE0}, {0x03, 0xE0, 0x11, 0x03, 0xE0}, {0x03, 0xE0, 0x00, 0x03, 0xE0},
  {0x03, 0xE0, 0x00, 0x03, 0xE0}, {0x03, 0xE0, 0x00, 0x03, 0xE0}, {0x03, 0xE0, 0x00, 0x03, 0xE0}, {0x03, 0xE0, 0x00, 0x03, 0xE0}, {0x03, 0xE0, 0x00, 0x03, 0xE0}, {0x03, 0xE0, 0x00, 0x03, 0xE0}, {0x03, 0xE0, 0x00, 0x03, 0xE0}, {0x03, 0xE0, 0x00, 0x03, 0xE0}, {0x03, 0xE0, 0x00, 0x03, 0xE0}, {0x03, 0xE0, 0x00, 0x03, 0xE0},
  {0x03, 0xE0, 0x00, 0x03, 0xE0}, {0x03, 0xE0, 0x11, 0x03, 0xE0}, {0x03, 0xE0, 0x73, 0x03, 0xE0}, {0x03, 0xE0, 0x7F, 0x03, 0xE0}, {0x03, 0xE0, 0xFF, 0x03, 0xE0}, {0x03, 0xE0, 0xFF, 0x03, 0xE0}, {0x03, 0xE0, 0x7F, 0x03, 0xE0}, {0x03, 0xE0, 0x73, 0x03, 0xE0}, {0x03, 0xE0, 0x11, 0x03, 0xE0}, {0x03, 0xE0, 0x00, 0x03, 0xE0},
  {0x03, 0xE0, 0x00, 0x03, 0xE0}, {0x03, 0xE0, 0x00, 0x03, 0xE0}, {0x03, 0xE0, 0x00, 0x03, 0xE0}, {0x03, 0xE0, 0x00, 0x03, 0xE0}, {0x03, 0xE0, 0x00, 0x03, 0xE0}, {0x03, 0xE0, 0x00, 0x03, 0xE0}, {0x03, 0xE0, 0x00, 0x03, 0xE0}, {0x07, 0xF0, 0x00, 0x03, 0xF0}, {0x07, 0xF0, 0x00, 0x07, 0xF0}, {0x0F, 0xF0, 0x00, 0x07, 0xF8},
};

// Function Declarations
void setBrightness(int brightness);
void receiveEvent(int howMany);
void receiveEventHandling();
void requestEvent();
void drawGear(int theta);

// Setup Function
void setup() {
  // Configure pins
  pinMode(SPI_CLOCK_PIN, OUTPUT);    // SPI Clock
  pinMode(SPI_MISO_PIN, INPUT);      // SPI MISO (not used in this code)
  pinMode(SPI_MOSI_PIN, OUTPUT);     // SPI MOSI
  pinMode(G_ENABLE_PIN, OUTPUT);     // G enable pin for 595
  pinMode(LATCH_PIN, OUTPUT);        // Latch pin for SPI
  pinMode(HALL_SENSOR_PIN_1, INPUT_PULLUP);  // Hall sensor input 1
  pinMode(HALL_SENSOR_PIN_2, INPUT_PULLUP);  // Hall sensor input 2 (INT0)

  // Enable INT0 as external interrupt (Hall sensor)
  EICRA |= (1 << ISC01);  // Set INT0 to trigger on falling edge
  EIMSK |= (1 << INT0);   // Enable INT0
  sei();                  // Enable global interrupts

  // Configure Timer1 for Fast PWM Mode
  noInterrupts();
  TCCR1A = B00100011;     // Clear OC1B on compare match, set OC1B at BOTTOM
  TCCR1B = B00011001;     // Fast PWM, no prescaling
  OCR1A = linePeriod;     // Set initial line period
  OCR1B = 62000;          // Initial brightness setting
  TIMSK1 = B00000001;     // Enable Timer1 Overflow Interrupt
  interrupts();

  // Initialize SPI
  SPI.begin();

  // Initialisiere I2C
  Wire.begin(4);                   // join I2C bus as slave for device #4
  Wire.onRequest(requestEvent);    // register request event
  Wire.onReceive(receiveEvent);    // register receive event


  // Initialize timestamps
  lastAnimationUpdateTime = millis();
  lastBrightnessUpdateTime = millis();
}

// Main Loop
void loop() {
  // Handle I2C receive event
  if (receiveEventFlag == 1) {
    receiveEventHandling();
  }

  // Update animation if enabled
  if (animationMode && (millis() - lastAnimationUpdateTime) > ANIMATION_UPDATE_INTERVAL) {
    animationAngle = (animationAngle + 1) % LINE_COUNT; // Increment angle and wrap around
    drawGear(animationAngle);                          // Draw gear at new angle   
    lastAnimationUpdateTime = millis();                // Update timestamp
  }

  // Update brightness if needed
  long timeSinceLastBrightnessUpdate = millis() - lastBrightnessUpdateTime;
  if ((timeSinceLastBrightnessUpdate > BRIGHTNESS_UPDATE_INTERVAL_SLOW) ||
      (timeSinceLastBrightnessUpdate > BRIGHTNESS_UPDATE_INTERVAL_FAST && updateBrightness)) {
    lastBrightnessUpdateTime = millis();
    updateBrightness = false;
    setBrightness(brightness); // Recalculate and set brightness
  }
}

// Timer1 Overflow Interrupt Service Routine
ISR(TIMER1_OVF_vect) {
  totalTimePerTurn += linePeriod;

  // Send line data via SPI
  SPI.beginTransaction(SPISettings(10000000, MSBFIRST, SPI_MODE0));
  digitalWrite(LATCH_PIN, LOW);
  SPI.transfer(lineData[lineCounter1][4]);
  SPI.transfer(lineData[lineCounter1][3]);
  SPI.transfer((lineData[lineCounter0][2] & 0x0F) + (lineData[lineCounter1][2] & 0xF0));
  SPI.transfer(lineData[lineCounter0][1]);
  SPI.transfer(lineData[lineCounter0][0]);
  digitalWrite(LATCH_PIN, HIGH);
  SPI.endTransaction();

  // Increment line counters
  lineCounter0 = (lineCounter0 + 1) % LINE_COUNT;
  lineCounter1 = (lineCounter1 + 1) % LINE_COUNT;
  lineCounter2++;
}

// Hall Sensor Interrupt Service Routine
ISR(INT0_vect) {
  totalTimePerTurn += ICR1; // Add time since last interrupt
  newLinePeriod = totalTimePerTurn / (LINE_COUNT - 1); // Calculate new line period

  // Update line period with smoothing
  if (labs(newLinePeriod - linePeriod) > 4) {
    linePeriod = newLinePeriod; // Large change: update immediately
    updateBrightness = true;    // Recalculate brightness
  } else {
    linePeriod = (7 * linePeriod + newLinePeriod) / 8; // Small change: smooth update
  }

  OCR1A = linePeriod - 1; // Update Timer1 compare register
  totalTimePerTurn = 0;   // Reset total time per turn

  // Reset line counters
  lineCounter1 = lineOffset;
  lineCounter0 = (lineOffset + 60) % LINE_COUNT;
  lineCounter2 = 0;

  // Clear interrupt flags
  TCNT1 = 0;      // Reset Timer1 counter
  TIFR1 |= 0x01;  // Clear Timer1 Overflow Flag
  EIFR |= 0x01;   // Clear INT0 Flag
}

// Set Brightness Function
void setBrightness(int brightness) {
  R = 30.1 / log10(linePeriod); // Calculate R-value for linearization
  pwmSet = linePeriod - pow(2, (brightness / R)) - 1; // Calculate PWM setting
  pwmSet = constrain(pwmSet, 10, linePeriod - 10);    // Constrain PWM setting
  OCR1B = pwmSet; // Update Timer1 compare register for brightness
}

// I2C Receive Event Handler
void receiveEvent(int howMany) {
  receiveEventFlag = 1; // Set flag to indicate I2C receive event
}

// I2C Receive Event Handling
void receiveEventHandling() {
  receiveEventFlag = 0; // Clear flag
  int messageCount = 0;

  // Read I2C data into buffer
  while (Wire.available()) {
    i2cBuffer[messageCount++] = Wire.read();
  }

  // Process received data
  if (messageCount == 6) {
    if (i2cBuffer[0] < LINE_COUNT) {
      // Update line data
      for (int j = 0; j < 5; j++) {
        lineData[i2cBuffer[0]][j] = i2cBuffer[j + 1];
      }
    } else if (i2cBuffer[0] == LINE_COUNT) {
      // Update brightness and animation mode
      brightness = i2cBuffer[1];
      animationMode = i2cBuffer[2] != 0;
    }
    lastReceivedLine = i2cBuffer[0]; // Update last received line index
  }
}

// I2C Request Event Handler
void requestEvent() {
  Wire.write(lastReceivedLine); // Send last received line index
}

// Draw Gear Function
void drawGear(int theta) {
  for (int i = 0; i < LINE_COUNT; i++) {
    int rowIndex = theta % GEAR_IMAGE_ROWS; // Calculate row index in gear image
    for (int j = 0; j < 5; j++) {
      lineData[i][j] = pgm_read_byte(&(gearImage[rowIndex][j])); // Copy gear data to line buffer
    }
    theta = (theta + 1) % LINE_COUNT; // Increment angle and wrap around
  }
}

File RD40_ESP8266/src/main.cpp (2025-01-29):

// =========================================================================================================================================
//                                                 Rotating Display RD40
//                                                    © Ludwin Monz
// License: Creative Commons Attribution - Non-Commercial - Share Alike (CC BY-NC-SA)
// you may use, adapt, share. If you share, "share alike".
// you may not use this software for commercial purposes 
// =========================================================================================================================================

#include <Arduino.h>
#include "my_ESP.h"
#include "RD_40.h"
#include "RD_40trafo.h"
#include "my_BMP.h"
#include "my_BMPtemplates.h"
#include "FlashFS.h"
#include "webInterface.h"

// =========================================================================================================================================
// 
//                                                        Rotating Display
//
// The program uses OOP in order to structure data and functions. These are the classes:
//
// 1. my_ESP
//    description:    the class manages the resources of the ESP microcontroller. 
//    key methods:    begin()                                         configures Wifi, i2c interface, sets time 
//                    getMyTime()                                     occupies the time and date attributes (see below) 
//                    myPassword()                                    returns Wifi Password which is being used
//                    mySSID()                                        returns Wifi SSID
//    key attributes: int Sec, int Min, int Hour, ...
//
// 2. RD_40
//    description:    the class provides the central rotating display object. It manages the data of the displayed image (one bit per LED), 
//                    etc. 
//                    The class has methods for displaying bitmaps and for transferring data to the display controller. 
//    key methods:    begin()                                         initialize display mode and data transfer to the display controller
//                    upload()                                        uploads display data to the display controller
//                    displayBMP(unsigned char bmp[][14])             displays bitmap
//    key attributes: clockMode, brightness
//
// 3. my_BMP
//    description:    this class generates bitmaps for the display. It provides methods for generating clock and weather screens, 
//                    as well as printing text on bitmaps. The bitmap shall be handed over to the RD40 object. 
//    key methods:    generateBMP(int mode, tm* tm, String* ssid)     generates bitmap according to mode, time, ssid
//    key attributes: bitmap[][]                                      this is a 110x110 pixel bitmap
//
// 4. webInterface
//    description:    the class manages the web user interface. It uses the AsyncWebServer library and runs in the background without any need for
//                    attention. The class provides certain attributes, which are set by the web interface:
//    key methods:    begin(String* ssid_)                            starts AsyncWebServer. ssid is displayed (not changed) in web interface
//    key attributes: int clockMode;                                  mode 0 = IP-address, mode 1 = analog clock, mode 2 = digital clock, mode 3 = logo clock, mode 4 = weather clock
//                    int brightness;                                 brightness value in %
//                    char apiKey[50]="";                             apiKey for openweathermap.org
//                    char location[50]="";                           location for openweathermap.org
//                    char country[20]="";                            country for openweathermap.org
//
// =========================================================================================================================================

my_ESP myESP;                                                // create instance of my_ESP
webInterface wi40;                                           // create instance of webInterface
RD_40 RD40;                                                  // create instance of RD_40
my_BMP myBMP;                                                // create instance of my_BMP

long lastWeatherUpdateTime = 0;                              // remember time of last weather update
int lastDisplayUpdateSecond = 0;                             // remember the second of last display update
int previousClockMode = 4;                                   // remember previous clockMode

// =========================================================================================================================

void setup() {
  // Serial port for debugging purposes
  Serial.begin(115200);

  myESP.begin();                            // initiates Wifi, I2C, time, and SPIFFS file management
  String ssid = myESP.ssid;                 // withdraw SSID
  wi40.begin(ssid);                         // start web server

  myESP.getMyTime();
  Serial.printf("Current Time: %d:%d:%d\n", myESP.Hour, myESP.Min, myESP.Sec);
}
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

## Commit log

2023-07-18 add bill of material (BOM)
    [bom rotating led display.xlsx]
2023-08-16 WORK IN PROGRESS: new SMD display PCB - DO NOT USE
    [RD40_display_SMD_V1.sch]
2023-08-17 new feature: time zone selection added
    [JLCPCB_BOM.xlsx]
2023-08-17 sample images added
2023-08-17 sample images - updated
2023-08-20 worked on microcontroller schematics
    [JLCPCB_BOM.xlsx, RD40_display_SMD.kicad_pcb, RD40_display_SMD.kicad_sch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]
2023-08-25 SMD circuit diagram further completed
    [ATmega328P.kicad_sch, ESP-12F.kicad_sch, JLCPCB_BOM.xlsx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]
2023-08-30 SMD PCB moved to a separate repository
    [ATmega328P.kicad_sch, ESP-12F.kicad_sch, JLCPCB_BOM.xlsx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]
2023-10-22 fix time zone table
    [SekCoilV2-B_Cu.gbr, SekCoilV2-B_Mask.gbr, SekCoilV2-B_Paste.gbr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]
2023-11-01 bug fix config weather
    [FlashFS.cpp, webInterface.cpp]
2025-01-23 minor additions to PCBs
    [RD40_PS_V1.kicad_pcb, RD40_PS_V1.kicad_sch, RD40_display_V1.kicad_pcb]
2025-01-28 cleanup of code, new gear animation
2025-01-31 Simplify print routine
2025-01-31 made print12x18 more robust
2025-02-15 add print10x15() function to RD40_simple_ESP8266

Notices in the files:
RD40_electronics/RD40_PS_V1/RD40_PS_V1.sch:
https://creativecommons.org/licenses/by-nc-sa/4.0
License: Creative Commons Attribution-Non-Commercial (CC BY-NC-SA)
